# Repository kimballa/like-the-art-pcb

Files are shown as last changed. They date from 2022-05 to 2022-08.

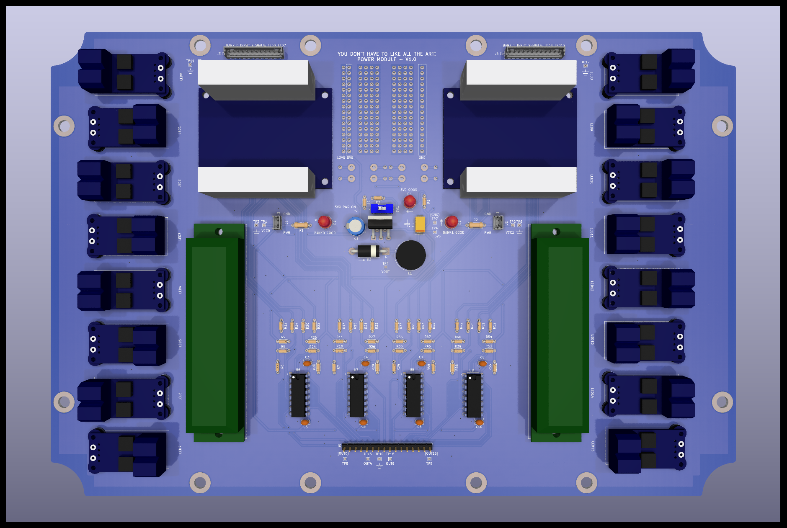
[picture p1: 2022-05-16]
lta-power-module/fab runs/lta-power-module-v1_0-2022-05-16/lta-power-module-v1_0 assembled board rendering.png

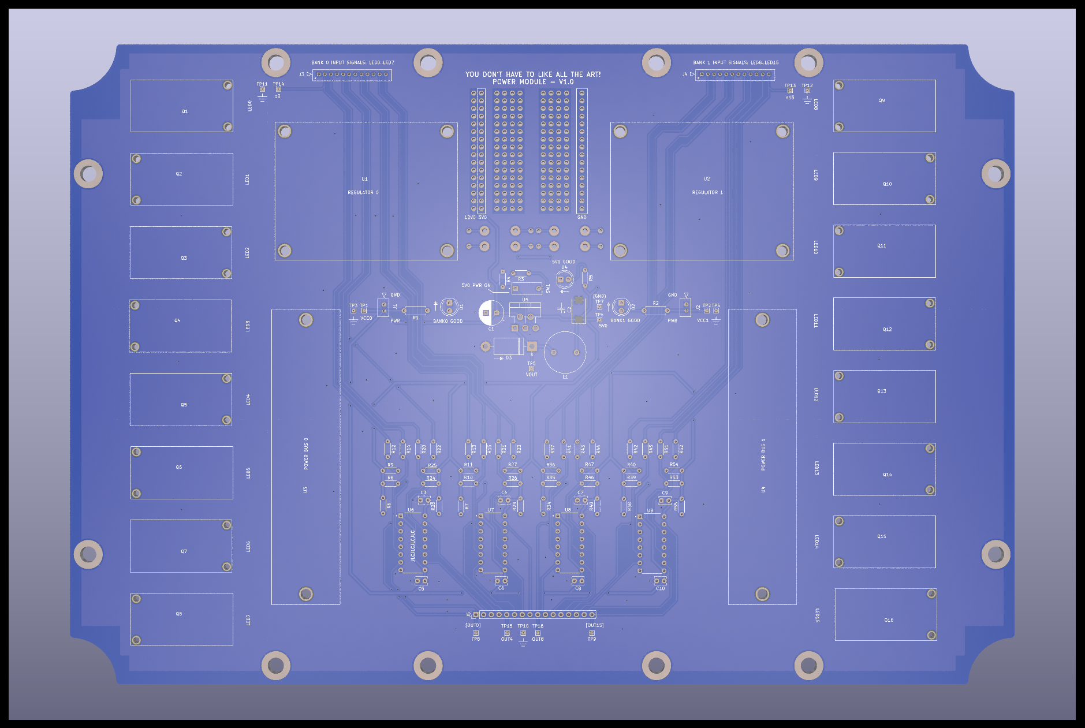
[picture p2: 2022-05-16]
lta-power-module/fab runs/lta-power-module-v1_0-2022-05-16/lta-power-module-v1_0 bare board rendering.png

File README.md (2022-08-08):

You Don't Have to Like All the Art! -- PCBs
===========================================

PCB designs and eCAD files for the "You Don't Have to Like All the Art!" project.

This system consists of two distinct circuit boards:

* `lta-logic-module` - The "logic" that determines when it's dark out / should be active, what
  messages to light up on the sign, manages PWM or other effects when displaying the sign, and
  also handles button inputs from users. Runs on a combination of 5V and 3V3. This is designed
  around a port for installing an Adafruit Feather M4 Express (ATSAMD51 / Cortex-M4) Arduino
  device. The rest of the circuitry:
  * Provides regulated 5V0 input voltage for the rest of this module
  * Manages a wide fanout of control and sense lines via I2C
  * Uses a phototransistor to sense when it is dark out, and thus the system should be active
    vs in standby mode
  * Combines the sign control lines with a global PWM signal and buffers the output before feeding
    to the power module.
* `lta-power-module` - The high-power circuits that actually drive the LED signs. This module is
  "dumb" and contains no combinational logic or more complex circuitry. Most of the board is used
  for mounting 3rd-party PCB submodules for high-amp 12V0 voltage regulation, distributing a
  power bus, and actually driving power MOSFETs linked to each sign's power wiring. The onboard
  circuitry:
  * Provides regulated 5V0 input voltage for the rest of the onboard circuitry
  * Displays condition of regulated 12V0 input power
  * Uses SN75374 low-side drivers to send control signals to the MOSFET modules
  * Contains a small integrated protoboard for in-field repairs and modifications

The `photodiode-sim` subproject is a simplified version of the `DARK` detection circuitry for use
with `ngspice` to understand the sensitivity of the logic signal to input current levels from the
phototransistor and the variable resistance of the potentiometer used as an in-field sensitivity
calibration input.

A third PCB (`mosfet-chip`) is a mini-PCB to connect two circuits via screw-terminals, switchable by
an onboard `IRLZ24` NMOS FET transistor activated by a separate gate pin. 16 of these are mounted on
the power module by #0 machine screws.

I originally used this
[High-Power Dual MOSFET Switch Module](https://protosupplies.com/product/high-power-dual-mosfet-switch-module/)
but found the screw terminals included were too unreliable. This PCB is footprint-compatible and
uses larger-gauge, higher-quality terminal blocks by Phoenix Contact. The `mosfet-chip/` directory
includes a panelized (2x3) layout suitable for PCBA and the BOM to enable assembly at JLCPCB.

Fabrication
-----------

All models are built with KiCAD 6. Each module contains a BOM spreadsheet for assembly with MPNs to
order from DigiKey or elsewhere as noted. Per-run fabrication gerbers are kept in versioned
subdirectories of each submodule project.

All modules are fabricated with the following parameters:

* 2 layers
* 1.6mm finished board thickness
* FR4-Tg130 core
* Both layers 1 oz copper thickness
* Blue soldermask, white silkscreen (these choices made only for aesthetic reasons and do not
  affect eng or mfg)

The logic module is fabricated with ENIG finish for reflow; the power module can be finished
with RoHS Pb-free HASL.

The logic module was fabricated by Elecrow and follows their design rules. Smallest
traces are 0.20mm. All trace separation >= 0.15mm.

The power module was fabricated by JLCPCB and follows their design rules. Smallest power module
traces and trace separations are 0.25mm / 0.20mm, which more than meets their capabilities.

Assembly
--------

Boards require only single-sided assembly.

The logic module is a mixed SMD/THT board and was assembled by Elecrow. Smallest reflow components
are 0603. Logic module ICs are SOIC (1.27mm pitch). Actual LEDs, resistors, and IC decoupling
capacitors do not follow the BOM strictly but instead use house parts (except as noted `Exact MPN
Only` in the BOM). More notes about logic module assembly are in `README-fab-and-pcba.txt` in
the logic module directory.

The power module is THT-only and intended for hand-soldered assembly. (A single 7343-metric / 2917
/ "size D" tantalum SMD capacitor for the 5V0 regulator can also be hand-soldered.)

The mosfet chips are a mixed SMD/THT assembly and were assembled by JLCPCB. BOM includes SPNs
for JLC's preferred supplier. Individual mini-PCBs are too small for automated SMD assembly,
so gerbers are supplied for a panelized 2x3 PCB layout, made with the Panelizer plugin for KiCAD 6.

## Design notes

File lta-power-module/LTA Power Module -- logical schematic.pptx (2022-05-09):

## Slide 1

Actual PCB-laid circuitry

2x MicroLatch 12-pin

2x12 c’tors w/
ext signals

Over header pins, 1 per FET driver
(Also to R + LED)

Power comes directly cabled into regulator, never through the board

12V regulator

12V regulator

Over flying wires

12-way terminal block

12V0

“PWR ON” LED

Also to board GND

“PWR ON” LED

Also to board GND

thru MicroLatch 2pin

5V0 regulator

thru MicroLatch 2pin

12-way terminal block

12V0

5V0

“go” @ 3V3

Over flying wires

4x SN75374

“go” @ 12V0

8x
FET drivers

To LED sign, via flying wires

8x
FET drivers

To LED sign, via flying wires

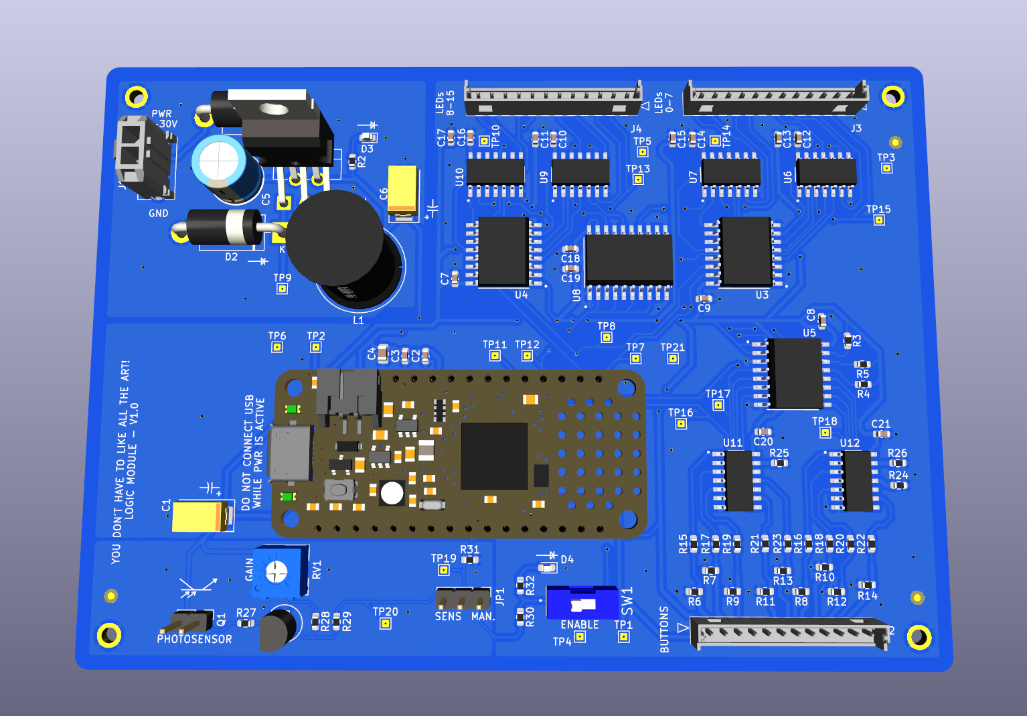
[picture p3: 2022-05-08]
lta-logic-module/fab runs/lta-logic-v1_0-2022-05-08/lta-logic-v1_0-2022-05-08-render.png

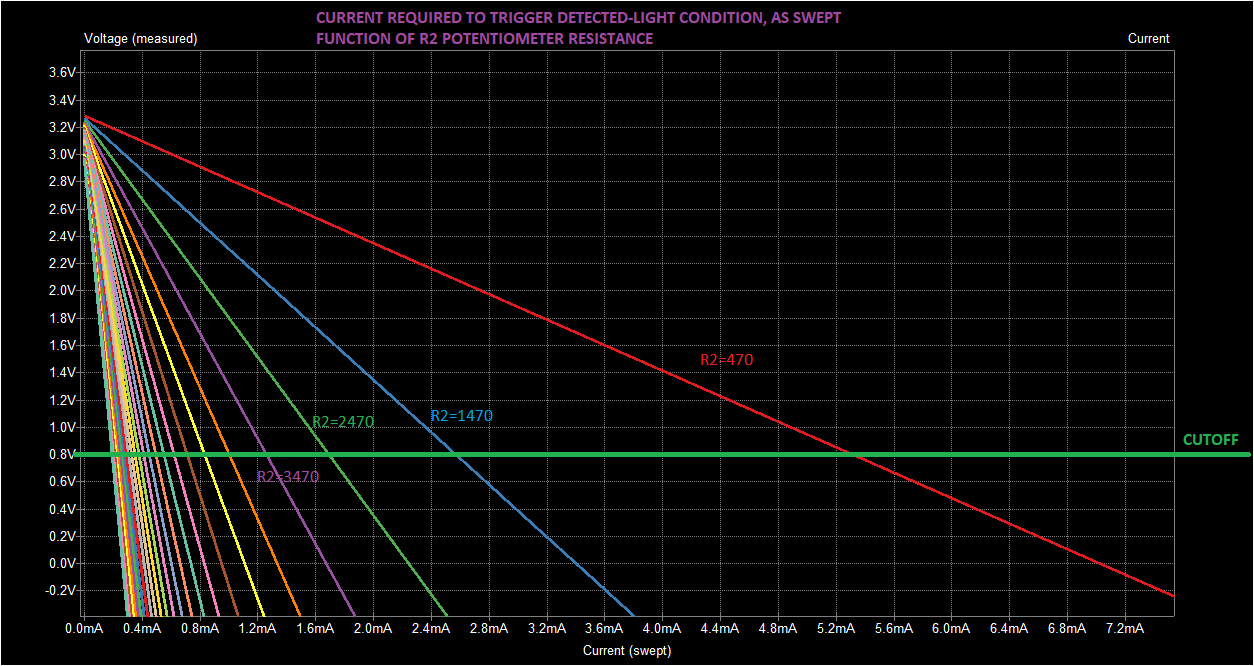
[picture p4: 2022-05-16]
photodiode-sim/sweep-analysis.png

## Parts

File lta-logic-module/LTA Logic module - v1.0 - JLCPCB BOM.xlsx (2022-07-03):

Reference | Value | Footprint | Datasheet | Comment | MANUFACTURER | MPN | SPN | Item Cost | QTY | BOM Cost
C1 | 22u | Capacitor_Tantalum_SMD:CP_EIA-7343-30_AVX-N | https://datasheets.kyocera-avx.com/X7RDielectric.pdf | 22u 10% >=16V 7343 ESR<=250mOhm solid tantalum | KYOCERA AVX | TPSD226K025R0200 | C444816 | $1.2335 | 1 | $1.2335 | SPN for 35V version; exact spec is C284839
C2, C7-C10, C12, C14, C16, C19-C21 | 100n | Capacitor_SMD:C_0603_1608Metric | https://datasheets.kyocera-avx.com/X7RDielectric.pdf | 100nF 5% 6.3V 0603 X7R ceramic; 20mOhm < ESR < 10 Ohm | KYOCERA | 06036C104JAT2A | C109474 | $0.0053 | 11 | $0.0583 | SPN for YAEGO equiv part @ 16V
C3, C11, C13, C15, C17, C18 | 1u | Capacitor_SMD:C_0603_1608Metric | https://datasheets.kyocera-avx.com/X7RDielectric.pdf | 1u 5% 16V 0603 X7R ceramic; 20mOhm < ESR < 10 Ohm | KYOCERA | 0603YC105JAT2A | C519560 | $0.0284 | 6 | $0.1704 | SPN for YAEGO equiv part
C4 | 4u7 | Capacitor_SMD:C_0805_2012Metric | https://datasheets.kyocera-avx.com/X7RDielectric.pdf | 4u7 5% 16V 0805 X7R ceramic; 20mOhm < ESR < 10 Ohm | KYOCERA | 0805YC475KAT2A | C513766 | $0.0272 | 1 | $0.0272 | SPN for alt. mfr; 25V 10%
C5 | 220u | Capacitor_THT:CP_Radial_D8.0mm_P3.50mm | https://content.kemet.com/datasheets/KEM_A4010_EST.pdf | 220u 20% 35V low-ESR (<=160mOhm), I_RMS>250mA aluminum | KEMET | EST227M035AG4AA | C440830 | $0.1048 | 1 | $0.1048 | SPN for Rubycon equivalent part
C6 | 68u | Capacitor_Tantalum_SMD:CP_EIA-7343-30_AVX-N | https://datasheets.kyocera-avx.com/TPS.pdf | 68u 10% AVX TPS 20V low-ESR (<=150mOhm) solid tantalum; exact MPN | KYOCERA AVX | TPSD686M020R0150 | C308898 | $2.9899 | 1 | $2.9899 | SPN for "E" case, 25V, 125 mOhm ESR (over-height; better voltage tol. / ESR; pricier)
D1 | SB5100 | Diode_THT:D_DO-201AD_P15.24mm_Horizontal | https://www.smc-diodes.com/propdf/SB5100%20N0092%20REV.B.pdf | Any 100V 5A Schottky diode, Vf <= 850mV | SMC Diode Solutions | SB5100 | C154717 | $0.5283 | 1 | $0.5283
D2 | SB530 | Diode_THT:D_DO-201AD_P15.24mm_Horizontal | https://www.vishay.com/docs/88721/sb520.pdf | 30V 5A Schottky diode, Vf <= 480mV. (Any SB530-xxx diode OK) | Vishay | SB530-E3/54 | C222506 | $0.8368 | 1 | $0.8368
D3 | PWR | LED_SMD:LED_0603_1608Metric | https://media.digikey.com/pdf/Data%20Sheets/Harvatek%20PDFs/B1931URO-20D000114U1930.pdf | Any Vf=2.0V I_test=20mA red LED OK | Harvatek | 3147-B1931URO-20D000114U1930CT-ND | C125099 | $0.0175 | 1 | $0.0175 | SPN for Lite-On LTST-C191KRKT
D4 | DARK_EN | LED_SMD:LED_0603_1608Metric | https://media.digikey.com/pdf/Data%20Sheets/Harvatek%20PDFs/B1931URO-20D000114U1930.pdf | Any Vf=2.0V I_test=20mA red LED OK | Harvatek | 3147-B1931URO-20D000114U1930CT-ND | C125099 | $0.0175 | 1 | $0.0175 | SPN for Lite-On LTST-C191KRKT
J1 | Molex-MicroFit_43650-0218 | Aaron_THT:Molex-Microfit-43650-0218 | https://www.molex.com/pdm_docs/ps/PS-43650.pdf | Molex Micro-Fit3, 2-pin | Molex | 436500218 | DNP |  | 1 | $0.0000
J2-J4 | Molex-MicroLatch_53253-1270 | Aaron_THT:Molex-MicroLatch-53253-1270 | https://www.molex.com/webdocs/datasheets/pdf/en-us/0532531270_PCB_HEADERS.pdf | Molex Micro-Latch, 12-pin | Molex | 532531270 | DNP |  | 3 | $0.0000
JP1 | Jumper_3_Open | Connector_PinHeader_2.54mm:PinHeader_1x03_P2.54mm_Vertical | ~ | Use 1x3 THT male pin header, gold mating, 2.54mm pitch |  |  | DNP |  | 1 | $0.0000
L1 | 150u | Aaron_THT:L_Radial_D13.5mm_P7.50mm | https://abracon.com/Magnetics/radial/AIUR-06.pdf | 150uH, Exact MFR/MPN required | Abracon LLC | AIUR-06-151K | DNP |  | 1 | $0.0000
Q1 | PT334-6B | Connector_PinHeader_2.54mm:PinHeader_1x02_P2.54mm_Vertical | https://media.digikey.com/pdf/Data%20Sheets/Everlight%20PDFs/PT334-6B.pdf | PT334 is externally-attached; mount 1x2 pin male header (2.54mm pitch, gold) here |  |  | DNP |  | 1 | $0.0000
Q2 | 2N3904 | Package_TO_SOT_THT:TO-92_Inline |  | Any 2N3904 TO-92 transistor OK | Central Semiconductor | 2N3904 PBFREE | C2081 | $0.0317 | 1 | $0.0317
R1, R6-R14, R24-R26 | 10K | Resistor_SMD:R_0603_1608Metric | ~ | 10K 0603 resistor; +/-1%; 1/10W | YAEGO | RC0603FR-0710KL | C25804 | $0.0012 | 13 | $0.0156 | SPN for JLC basic part - UNI-ROYAL equiv
R2 | 330R | Resistor_SMD:R_0603_1608Metric | ~ | 330R 0603 resistor; +/-1%; 1/10W | YAEGO | RC0603FR-07330RL | C23138 | $0.0012 | 1 | $0.0012 | SPN for JLC basic part - UNI-ROYAL equiv
R3-R5, R27, R30 | 4K7 | Resistor_SMD:R_0603_1608Metric | ~ | 4K7 0603 resistor; +/-1%; 1/10W | YAEGO | RC0603FR-074K7L | C23162 | $0.0012 | 5 | $0.0060 | SPN for JLC basic part - UNI-ROYAL equiv
R15-R23, R28 | 470R | Resistor_SMD:R_0603_1608Metric | ~ | 470R 0603 resistor; +/-1%; 1/10W | YAEGO | RC0603FR-07470RL | C23179 | $0.0012 | 10 | $0.0120 | SPN for JLC basic part - UNI-ROYAL equiv
R29 | 220R | Resistor_SMD:R_0603_1608Metric | ~ | 220R 0603 resistor; +/-1%; 1/10W | YAEGO | RC0603FR-07220RL | C22962 | $0.0012 | 1 | $0.0012 | SPN for JLC basic part - UNI-ROYAL equiv
R31 | 220K | Resistor_SMD:R_0603_1608Metric | ~ | 220K 0603 resistor; +/-1%; 1/10W | YAEGO | RC0603FR-07220KL | C22961 | $0.0012 | 1 | $0.0012 | SPN for JLC basic part - UNI-ROYAL equiv
R32 | 120R | Resistor_SMD:R_0603_1608Metric | ~ | 120R 0603 resistor; +/-1%; 1/10W | YAEGO | RC0603FR-07120RL | C22787 | $0.0012 | 1 | $0.0012 | SPN for JLC basic part - UNI-ROYAL equiv
RV1 | 25K | Aaron_THT:TRIM_3362P | https://www.bourns.com/docs/Product-Datasheets/3362.pdf | Any 25KOhm trimpot w/ same footprint OK | Bourns | 3362P-1-253LF | C81264 | $0.2587 | 1 | $0.2587 | SPN for 50 KOhm version
SW1 | SW_SPST | Aaron_THT:CUI-DIP-SW_DS01-254-x-01xx | https://www.cuidevices.com/product/resource/ds01-254.pdf | Any 1x SPST THT dip switch w/ same footprint OK | CUI Devices | DS01-254-S-01BE | C129067 | $0.2913 | 1 | $0.2913 | SPN for alt. mfr
U1 | Feather_M4_Express | aaron-imported-parts:Arduino_Feather_M4_Express_PinHeaders |  | Use 1x16 and 1x12 female THT headers, gold mating, 2.54mm pitch, 6.5--8.0mm tall |  |  | DNP |  | 1 | $0.0000
U2 | LM2595T-5 | Aaron_THT:TO-220-5_P3.4x3.7mm_StaggerOdd_Lead3.8mm_Vertical-SilkFix | http://www.ti.com.cn/cn/lit/ds/symlink/lm2595.pdf | Exact MFR/MPN required | Texas Instruments | LM2595T-5.0/NOPB | C2868897 | $3.7600 | 1 | $3.7600 | no stock; can be hand-soldered @ home.
U3-U5 | PCF8574DW | Aaron_TI_Parts:TI_SOIC_DW0016A | https://www.ti.com/lit/ds/symlink/pcf8574.pdf | Exact MFR/MPN required | Texas Instruments | PCF8574DW | C7605 | $1.7709 | 3 | $5.3127 | SPN for NXP equiv; 2x-check footprint. Exact MPN is C1542490 but no stock
U6, U7, U9, U10 | SN74LVC00AD | Aaron_TI_Parts:TI_SOIC_D_R-PDSO-G14 | https://www.ti.com/lit/ds/symlink/sn74lvc00a.pdf | Exact MFR/MPN required | Texas Instruments | SN74LVC00AD | C485072 | $0.2214 | 4 | $0.8856
U8 | SN74LVC244ADWR | Aaron_TI_Parts:TI_SOIC_DW0020A | https://www.ti.com/lit/ds/symlink/sn74lvc244a.pdf | Exact MFR/MPN required; -ADW or -ADWR packaging OK. | Texas Instruments | SN74LVC244ADWR | C507250 | $0.4869 | 1 | $0.4869
U11, U12 | SN74LVC14AD | Aaron_TI_Parts:TI_SOIC_D_R-PDSO-G14 | https://www.ti.com/lit/ds/symlink/sn74lvc14a.pdf | Exact MFR/MPN required | Texas Instruments | SN74LVC14AD | C133541 | $0.2196 | 2 | $0.4392

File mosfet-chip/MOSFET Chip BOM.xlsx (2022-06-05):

Reference | Value | Footprint | Datasheet | Comment | JLCPCB_PN | MANUFACTURER | MPN | SPN | Qty
D1 | XL-1608SURC-06 | LED_SMD:LED_0603_1608Metric | https://datasheet.lcsc.com/lcsc/2012301032_XINGLIGHT-XL-1608SURC-06_C965799.pdf |  | C965799 | XINGLIGHT | XL-1608SURC-06 |  | 1
> H1, H2 | MountingHole | Aaron_Pads:MountingHole_80mil | ~ |  |  |  |  |  | 2
J1 | Conn_01x02 | Connector_PinHeader_2.54mm:PinHeader_1x02_P2.54mm_Vertical | ~ | 0.1" gold male header pins | DNP | TE Connectivity AMP Connectors | 5-146858-1 | A105469CT-ND | 1
> J2, J3 | Screw_Terminal_01x02 | Aaron_Phoenix_Parts:Phoenix_1x02_1711725 | https://media.digikey.com/pdf/Data%20Sheets/Phoenix%20Contact%20PDFs/1711725.pdf |  | C89120 | Phoenix Contact | 1711725 | 277-1027-ND | 2
Q1 | ${FET_PART} | Package_TO_SOT_THT:TO-220-3_Vertical | https://www.infineon.com/dgdl/irlz34npbf.pdf?fileId=5546d462533600a40153567206892720 |  | C513144 | Infineon | IRLZ34NPbF | IRLZ34NPBF-ND | 1
R1 | 100R | Resistor_SMD:R_0603_1608Metric |  | 100R 1% 1/10W | C22775 | UNI-ROYAL | 0603WAF1000T5E |  | 1
R2 | 10K | Resistor_SMD:R_0603_1608Metric |  | 10K 1% 1/10W | C25804 | UNI-ROYAL | 0603WAF1002T5E |  | 1
R3 | 3K3 | Resistor_SMD:R_0603_1608Metric |  | 3K3 1% 1/10W | C22978 | UNI-ROYAL | 0603WAF3301T5E |  | 1

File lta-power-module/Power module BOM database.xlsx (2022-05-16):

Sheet: PCB BOM
Reference | Value | Footprint | Datasheet | Comment | MANUFACTURER | MPN | SPN | Supplier | Qty
C1 | 220u | Capacitor_THT:CP_Radial_D8.0mm_P3.50mm | https://content.kemet.com/datasheets/KEM_A4010_EST.pdf | 220u 20% 35V low-ESR (<=160mOhm), I_RMS>250mA aluminum | KEMET | EST227M035AG4AA | 399-6615-ND | DigiKey | 1
C2 | 68u | Capacitor_Tantalum_SMD:CP_EIA-7343-30_AVX-N_Pad2.25x2.55mm_HandSolder | https://datasheets.kyocera-avx.com/TPS.pdf | 68u 10% AVX TPS 20V low-ESR (<=150mOhm) solid tantalum; exact MPN | KYOCERA AVX | TPSD686M020R0150 | 478-9217-1-ND | DigiKey | 1
> C3-C10 | 1u | Capacitor_THT:C_Disc_D3.8mm_W2.6mm_P2.50mm | https://connect.kemet.com:7667/gateway/IntelliData-ComponentDocumentation/1.0/download/datasheet/C315C105K3R5TA7303 | 1u X7R 25V low-ESR THT | KEMET | C315C105K3R5TA7303 | 399-C315C105K3R5TA7303CT-ND | DigiKey | 8
D1 | PWR0 | Aaron_THT:LED_D5.0mm_SilkFix | https://cree-led.com/media/documents/C5SMF-RJF-RJE-GJF-GJE-BJF-BJE-1240.pdf | Vf=2.0V I_test=20mA red LED 5mm THT | CreeLED | C5SMF-RJF-CT0W0BB1 | C5SMF-RJF-CT0W0BB1-ND | DigiKey | 1
D2 | PWR1 | Aaron_THT:LED_D5.0mm_SilkFix | https://cree-led.com/media/documents/C5SMF-RJF-RJE-GJF-GJE-BJF-BJE-1240.pdf | Vf=2.0V I_test=20mA red LED 5mm THT | CreeLED | C5SMF-RJF-CT0W0BB1 | C5SMF-RJF-CT0W0BB1-ND | DigiKey | 1
D3 | SB530 | Diode_THT:D_DO-201AD_P15.24mm_Horizontal | https://www.vishay.com/docs/88721/sb520.pdf | 30V 5A Schottky diode, Vf <= 480mV. (Any SB530-xxx diode OK) | Vishay | SB530-E3/54 | SB530-E3/54GICT-ND | DigiKey | 1
D4 | 5V0PWR | Aaron_THT:LED_D5.0mm_SilkFix | https://cree-led.com/media/documents/C5SMF-RJF-RJE-GJF-GJE-BJF-BJE-1240.pdf | Vf=2.0V I_test=20mA red LED 5mm THT | CreeLED | C5SMF-RJF-CT0W0BB1 | C5SMF-RJF-CT0W0BB1-ND | DigiKey | 1
> H1-H12 | MountingHole_Pad | MountingHole:MountingHole_5.3mm_M5_ISO7380_Pad | ~ | M5 screw mounting hole, ISO 7380 pad |  |  |  |  | 12
> J1, J2 | Molex-MicroLatch-53253-0270 | Aaron_THT:Molex-MicroLatch-53253-0270 | https://www.molex.com/webdocs/datasheets/pdf/en-us/0532530270_PCB_HEADERS.pdf | 2-pin header for power (regulator out) | Molex | 532530270 | WM19004-ND | DigiKey | 2
> J3, J4 | Molex-MicroLatch-53253-1270 | Aaron_THT:Molex-MicroLatch-53253-1270 | https://www.molex.com/webdocs/datasheets/pdf/en-us/0532531270_PCB_HEADERS.pdf | 12-pin signal connector | Molex | 532531270 | WM24308-ND | DigiKey | 2
J5 | Conn_01x16 | Connector_PinHeader_2.54mm:PinHeader_1x16_P2.54mm_Vertical | ~ | standard male 2.54mm gold THT header pin row | TE Connectivity AMP Connectors | 5-146858-1 | A105469CT-ND | DigiKey | 1
> J6, J8-J17, J19, J20, J22-J31, J34, J36-J45, J47, J48, J50-J59, J61-J69, J71, J72, J74-J83, J86, J88-J97, J99-J107, J109, J110, J112-J121, J123, J124, J126-J135, J138, J140-J149, J152-J159, J161, J162, J164-J173, J176, J178-J187, J190, J192-J201, J204-J211, J214, J216-J218, J220-J222, J224-J226, J228, J229 | Conn_01x01 | Aaron_Pads:1mm_PTH_No_Silk | ~ | standard 1mm PTH for prototyping |  |  |  |  | 184
> J18, J46, J60, J70, J98, J108, J122, J160 | Conn_01x01 | Aaron_Pads:1.6mm_PTH_No_Silk | ~ | larger 1.6mm holes for DO201 diodes, larger capacitors |  |  |  |  | 8
L1 | 150u | Aaron_THT:L_Radial_D13.5mm_P7.50mm | https://abracon.com/Magnetics/radial/AIUR-06.pdf | 150uH, Exact MFR/MPN required | Abracon LLC | AIUR-06-151K | 535-13029-ND | DigiKey | 1
> Q1-Q16 | Dual_MOSFET_Switch_Module | lta-power-footprints:Dual_MOSFET_Driver | https://protosupplies.com/product/high-power-dual-mosfet-switch-module/ | Dual MOSFET driver board w/ mounting holes |  |  | B07XJSRY6B | Amazon | 16
> R1, R2 | 1K, 1/4W | Resistor_THT:R_Axial_DIN0207_L6.3mm_D2.5mm_P7.62mm_Horizontal |  | 1K THT resistor; +/-5%; 1/4W | Stackpole | CF14JT1K00 | CF14JT1K00CT-ND | DigiKey | 2
> R3, R4 | 10K | Resistor_THT:R_Axial_DIN0204_L3.6mm_D1.6mm_P5.08mm_Horizontal | ~ | 10K THT resistor; +/-5%; 1/8W | Stackpole | CF18JT10K0 | CF18JT10K0CT-ND | DigiKey | 2
R5 | 330R | Resistor_THT:R_Axial_DIN0204_L3.6mm_D1.6mm_P5.08mm_Horizontal |  | 330R THT resistor; +/-5%; 1/8W | Stackpole | CF18JT330R | CF18JT330RCT-ND | DigiKey | 1
> R12-R15, R20-R23, R37, R41-R45, R51, R52 | 33R | Resistor_THT:R_Axial_DIN0204_L3.6mm_D1.6mm_P5.08mm_Horizontal | ~ | 33R THT resistor; +/-5%; 1/8W | Stackpole | CF18JT33R0 | CF18JT33R0CT-ND | DigiKey | 16
> R6, R7, R28, R29, R34, R38, R48, R55 | 220R | Resistor_THT:R_Axial_DIN0204_L3.6mm_D1.6mm_P5.08mm_Horizontal | ~ | 220R THT resistor; +/-5%; 1/8W | Stackpole | CF18JT220R | CF18JT220RCT-ND | DigiKey | 8
> R8-R11, R24-R27, R35, R36, R39, R40, R46, R47, R53, R54 | 2K2 | Resistor_THT:R_Axial_DIN0204_L3.6mm_D1.6mm_P5.08mm_Horizontal | ~ | 2K2 THT resistor; +/-5%; 1/8W | Stackpole | CF18JT2K20 | CF18JT2K20CT-ND | DigiKey | 16
SW1 | SW_SPST | Aaron_THT:CUI-DIP-SW_DS01-254-x-01xx | https://www.cuidevices.com/product/resource/ds01-254.pdf | Any 1x SPST THT dip switch w/ same footprint OK | CUI Devices | DS01-254-S-01BE | 2223-DS01-254-S-01BE-ND | DigiKey | 1
> TP1-TP16 | TestPoint_Flag | Aaron_THT:TestPoint_THTPad_1.0x1.0mm_Drill0.3mm | ~ |  |  |  |  |  | 16
> U1, U2 | DIYMORE_20A_Step_Down | lta-power-footprints:12V_regulator | https://www.amazon.com/dp/B07Y7YB14L?psc=1&ref=ppx_yo2ov_dt_b_product_details |  | DIYMORE |  | B07Y7YB14L | Amazon | 2
> U3, U4 | OONO_16A_12pos_Terminal_Block | lta-power-footprints:12-way_power_distribution_bus | https://www.amazon.com/dp/B08TBXQ7H6?psc=1&smid=A2OVMUS055KMW5&ref_=chk_typ_imgToDp |  |  |  | B08TBXQ7H6 | Amazon | 2
U5 | LM2595T-5 | Aaron_THT:TO-220-5_P3.4x3.7mm_StaggerOdd_Lead3.8mm_Vertical-SilkFix | http://www.ti.com.cn/cn/lit/ds/symlink/lm2595.pdf | Exact MFR/MPN required | Texas Instruments | LM2595T-5.0/NOPB | LM2595T-5.0/NOPB-ND | DigiKey | 1
> U6-U9 | SN75374N | Aaron_TI_Parts:TI_N_R-PDIP-T16 | https://www.ti.com/lit/ds/symlink/sn75374.pdf |  | Texas Instruments | SN75374N | 296-34130-5-ND | DigiKey | 4

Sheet: Assembly BOM Items
Reference | Value | Description | Comment | Datasheet | MANUFACTURER | MPN | SPN | Supplier | Qty
J1, J2, J3, J4 |  | Micro-Latch female crimp terminal, 24--30AWG | Get a bunch of overage. Fragile, and great price break. Get like 200. |  | Molex | 502128000 | WM4561CT-ND | DigiKey | 64 | includes 1 power + 1 logic pcb's worth.
J1, J2 |  | Micro-Latch 2-pin female crimp housing for connector |  |  | Molex | 510650200 | WM19009-ND | DigiKey | 2
J3, J4 + 3xLOGIC |  | Micro-Latch 12-pin female crimp housing for connector |  |  | Molex | 510651200 | WM24300-ND | DigiKey | 5 | 2 for power PCB, 3 for logic PCB
(for logic board) |  | Micro-Fit 3.0 Female-to-Pigtail Cable Assembly, 2 leads, 150.00mm | For logic board; 18AWG | https://www.molex.com/webdocs/datasheets/pdf/en-us/2147511021_CABLE_ASSEMBLIES.pdf | Molex | 2147511021 | 900-2147511021-ND | DigiKey | 2
(spares for logic board) |  | PT334-6B photo-transistor | Spares |  | Everlight Electronics Co | PT334-6B | 1080-1158-ND | DigiKey | 4

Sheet: DigiKey-order-2022-05-10
Purpose | Part | MPN | SPN | Qty/Board | Overage | Total Qty | Digikey Order Line
PCBA BOM | 220u 20% 35V low-ESR (<=160mOhm), I_RMS>250mA aluminum | EST227M035AG4AA | 399-6615-ND | 1 | 2 | 4 | 4,399-6615-ND,
PCBA BOM | 68u 10% AVX TPS 20V low-ESR (<=150mOhm) solid tantalum; exact MPN | TPSD686M020R0150 | 478-9217-1-ND | 1 | 2 | 4 | 4,478-9217-1-ND,
PCBA BOM | 1u X7R 25V low-ESR THT | C315C105K3R5TA7303 | 399-C315C105K3R5TA7303CT-ND | 8 | 4 | 20 | 20,399-C315C105K3R5TA7303CT-ND,
PCBA BOM | Vf=2.0V I_test=20mA red LED 5mm THT | C5SMF-RJF-CT0W0BB1 | C5SMF-RJF-CT0W0BB1-ND | 3 | 4 | 10 | 10,C5SMF-RJF-CT0W0BB1-ND,
PCBA BOM | 30V 5A Schottky diode, Vf <= 480mV. (Any SB530-xxx diode OK) | SB530-E3/54 | SB530-E3/54GICT-ND | 1 | 1 | 3 | 3,SB530-E3/54GICT-ND,
PCBA BOM | Molex 2-pin microlatch | 532530270 | WM19004-ND | 2 | 1 | 5 | 5,WM19004-ND,
PCBA BOM | Molex 12-pin microlatch | 532531270 | WM24308-ND | 2 | 1 | 5 | 5,WM24308-ND,
PCBA BOM | standard male 2.54mm gold THT header pin row | 5-146858-1 | A105469CT-ND | 16 | 68 | 100 | 100,A105469CT-ND,
PCBA BOM | 150uH, Exact MFR/MPN required | AIUR-06-151K | 535-13029-ND | 1 | 1 | 3 | 3,535-13029-ND,
PCBA BOM | 1K THT resistor; +/-5%; 1/4W | CF14JT1K00 | CF14JT1K00CT-ND | 2 | 6 | 10 | 10,CF14JT1K00CT-ND,
PCBA BOM | 10K THT resistor; +/-5%; 1/8W | CF18JT10K0 | CF18JT10K0CT-ND | 2 | 6 | 10 | 10,CF18JT10K0CT-ND,
PCBA BOM | 330R THT resistor; +/-5%; 1/8W | CF18JT330R | CF18JT330RCT-ND | 1 | 8 | 10 | 10,CF18JT330RCT-ND,
PCBA BOM | 220R THT resistor; +/-5%; 1/8W | CF18JT220R | CF18JT220RCT-ND | 8 | 9 | 25 | 25,CF18JT220RCT-ND,
PCBA BOM | 33R THT resistor; +/-5%; 1/8W | CF18JT33R0 | CF18JT33R0CT-ND | 16 | 18 | 50 | 50,CF18JT33R0CT-ND,
PCBA BOM | 2K2 THT resistor; +/-5%; 1/8W | CF18JT2K20 | CF18JT2K20CT-ND | 16 | 18 | 50 | 50,CF18JT2K20CT-ND,
PCBA BOM | 1x SPST THT dip switch | DS01-254-S-01BE | 2223-DS01-254-S-01BE-ND | 1 | 1 | 3 | 3,2223-DS01-254-S-01BE-ND,
PCBA BOM | 5V buck regulator | LM2595T-5.0/NOPB | LM2595T-5.0/NOPB-ND | 1 | 1 | 3 | 3,LM2595T-5.0/NOPB-ND,
PCBA BOM | FET driver | SN75374N | 296-34130-5-ND | 4 | 2 | 10 | 10,296-34130-5-ND,
Tools | trimpot adjuster tool | H-90 | H90-ND | 0 | 1 | 1 | 1,H90-ND,
general order | Basic NPN transistor | BC546BTF | BC546BTFCT-ND | 0 | 4 | 4 | 4,BC546BTFCT-ND,
general order | Basic NPN transistor | 2N3904 PBFREE | 1514-2N3904PBFREE-ND | 0 | 4 | 4 | 4,1514-2N3904PBFREE-ND,
general order | Basic NPN transistor | PN2222TF | PN2222TFCT-ND | 0 | 4 | 4 | 4,PN2222TFCT-ND,
general order | Basic PNP transistor | PN2907ATF | PN2907ATFCT-ND | 0 | 4 | 4 | 4,PN2907ATFCT-ND,
general order | Basic PNP transistor | BC557BTF | BC557BTFCT-ND | 0 | 4 | 4 | 4,BC557BTFCT-ND,
general order | Basic PNP transistor | 2N3906-G | 641-1946-ND | 0 | 4 | 4 | 4,641-1946-ND,
general order | 25KOhm single-turn trimpot | 3362P-1-253LF | 3362P-253LF-ND | 0 | 2 | 2 | 2,3362P-253LF-ND,
general order | 12V 1A fixed buck regulator | LM2675N-12/NOPB | LM2675N-12/NOPB-ND | 0 | 1 | 1 | 1,LM2675N-12/NOPB-ND,
Extended PCBA | Micro-Latch female crimp terminal, 24--30AWG | 502128000 | WM4561CT-ND | 28 | 144 | 200 | 200,WM4561CT-ND,
Extended PCBA | Micro-Latch 2-pin female crimp housing for connector | 510650200 | WM19009-ND | 2 | 1 | 5 | 5,WM19009-ND,
Extended PCBA | Micro-Latch 12-pin female crimp housing for connector | 510651200 | WM24300-ND | 2 | 3 | 7 | 7,WM24300-ND,
general order | Micro-Fit 3.0 Female-to-Pigtail Cable Assembly, 2 leads, 150.00mm | 2147511021 | 900-2147511021-ND | 0 | 2 | 2 | 2,900-2147511021-ND,
general order | PT334-6B photo-transistor | PT334-6B | 1080-1158-ND | 0 | 4 | 4 | 4,1080-1158-ND,

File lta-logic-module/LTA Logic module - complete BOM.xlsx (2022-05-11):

Reference | Value | Footprint | Datasheet | Comment | MANUFACTURER | MPN | QTY
C1 | 22u | Capacitor_Tantalum_SMD:CP_EIA-7343-30_AVX-N | https://datasheets.kyocera-avx.com/X7RDielectric.pdf | 22u 10% >=16V 7343 ESR<=250mOhm solid tantalum | KYOCERA AVX | TPSD226K025R0200 | 1
> C2, C7-C10, C12, C14, C16, C19-C21 | 100n | Capacitor_SMD:C_0603_1608Metric | https://datasheets.kyocera-avx.com/X7RDielectric.pdf | 100nF 5% 6.3V 0603 X7R ceramic; 20mOhm < ESR < 10 Ohm | KYOCERA | 06036C104JAT2A | 11
> C3, C11, C13, C15, C17, C18 | 1u | Capacitor_SMD:C_0603_1608Metric | https://datasheets.kyocera-avx.com/X7RDielectric.pdf | 1u 5% 16V 0603 X7R ceramic; 20mOhm < ESR < 10 Ohm | KYOCERA | 0603YC105JAT2A | 6
C4 | 4u7 | Capacitor_SMD:C_0805_2012Metric | https://datasheets.kyocera-avx.com/X7RDielectric.pdf | 4u7 5% 16V 0805 X7R ceramic; 20mOhm < ESR < 10 Ohm | KYOCERA | 0805YC475KAT2A | 1
C5 | 220u | Capacitor_THT:CP_Radial_D8.0mm_P3.50mm | https://content.kemet.com/datasheets/KEM_A4010_EST.pdf | 220u 20% 35V low-ESR (<=160mOhm), I_RMS>250mA aluminum | KEMET | EST227M035AG4AA | 1
C6 | 68u | Capacitor_Tantalum_SMD:CP_EIA-7343-30_AVX-N | https://datasheets.kyocera-avx.com/TPS.pdf | 68u 10% AVX TPS 20V low-ESR (<=150mOhm) solid tantalum; exact MPN | KYOCERA AVX | TPSD686M020R0150 | 1
D1 | SB5100 | Diode_THT:D_DO-201AD_P15.24mm_Horizontal | https://www.smc-diodes.com/propdf/SB5100%20N0092%20REV.B.pdf | Any 100V 5A Schottky diode, Vf <= 850mV | SMC Diode Solutions | SB5100 | 1
D2 | SB530 | Diode_THT:D_DO-201AD_P15.24mm_Horizontal | https://www.vishay.com/docs/88721/sb520.pdf | 30V 5A Schottky diode, Vf <= 480mV. (Any SB530-xxx diode OK) | Vishay | SB530-E3/54 | 1
D3 | PWR | LED_SMD:LED_0603_1608Metric | https://media.digikey.com/pdf/Data%20Sheets/Harvatek%20PDFs/B1931URO-20D000114U1930.pdf | Vf=2.0V I_test=20mA red LED | Harvatek | 3147-B1931URO-20D000114U1930CT-ND | 1
D4 | DARK_EN | LED_SMD:LED_0603_1608Metric | https://media.digikey.com/pdf/Data%20Sheets/Harvatek%20PDFs/B1931URO-20D000114U1930.pdf | Vf=2.0V I_test=20mA red LED | Harvatek | 3147-B1931URO-20D000114U1930CT-ND | 1
> FID1-FID3 | Fiducial | Fiducial:Fiducial_1mm_Mask2mm | ~ |  |  |  | 3
> H1-H4 | MountingHole_Pad | MountingHole:MountingHole_2.2mm_M2_ISO7380_Pad | ~ |  |  |  | 4
J1 | Molex-MicroFit_43650-0218 | Aaron_THT:Molex-Microfit-43650-0218 | https://www.molex.com/pdm_docs/ps/PS-43650.pdf | Molex Micro-Fit3, 2-pin | Molex | 436500218 | 1
> J2-J4 | Molex-MicroLatch_53253-1270 | Aaron_THT:Molex-MicroLatch-53253-1270 | https://www.molex.com/webdocs/datasheets/pdf/en-us/0532531270_PCB_HEADERS.pdf | Molex Micro-Latch, 12-pin | Molex | 532531270 | 3
JP1 | Jumper_3_Open | Connector_PinHeader_2.54mm:PinHeader_1x03_P2.54mm_Vertical | ~ | Use 1x3 THT male pin header, gold mating, 2.54mm pitch |  |  | 1
L1 | 150u | Aaron_THT:L_Radial_D13.5mm_P7.50mm | https://abracon.com/Magnetics/radial/AIUR-06.pdf | 150uH, Exact MFR/MPN required | Abracon LLC | AIUR-06-151K | 1
Q1 | PT334-6B | Connector_PinHeader_2.54mm:PinHeader_1x02_P2.54mm_Vertical | https://media.digikey.com/pdf/Data%20Sheets/Everlight%20PDFs/PT334-6B.pdf | PT334 is externally-attached; mount 1x2 pin male header (2.54mm pitch, gold) here | Everlight | PT334-6B | 1
Q2 | 2N3904 | Package_TO_SOT_THT:TO-92_Inline |  | Any 2N3904 TO-92 transistor OK | Central Semiconductor | 2N3904 PBFREE | 1
> R1, R6-R14, R24-R26 | 10K | Resistor_SMD:R_0603_1608Metric | ~ | 10K 0603 resistor; +/-1%; 1/10W | YAEGO | RC0603FR-0710KL | 13
R2 | 330R | Resistor_SMD:R_0603_1608Metric | ~ | 330R 0603 resistor; +/-1%; 1/10W | YAEGO | RC0603FR-07330RL | 1
> R3-R5, R27, R30 | 4K7 | Resistor_SMD:R_0603_1608Metric | ~ | 4K7 0603 resistor; +/-1%; 1/10W | YAEGO | RC0603FR-074K7L | 5
> R15-R23, R28 | 470R | Resistor_SMD:R_0603_1608Metric | ~ | 470R 0603 resistor; +/-1%; 1/10W | YAEGO | RC0603FR-07470RL | 10
R29 | 220R | Resistor_SMD:R_0603_1608Metric | ~ | 220R 0603 resistor; +/-1%; 1/10W | YAEGO | RC0603FR-07220RL | 1
R31 | 220K | Resistor_SMD:R_0603_1608Metric | ~ | 220K 0603 resistor; +/-1%; 1/10W | YAEGO | RC0603FR-07220KL | 1
R32 | 120R | Resistor_SMD:R_0603_1608Metric | ~ | 120R 0603 resistor; +/-1%; 1/10W | YAEGO | RC0603FR-07120RL | 1
RV1 | 25K | Aaron_THT:TRIM_3362P | https://www.bourns.com/docs/Product-Datasheets/3362.pdf | Any 25KOhm trimpot w/ same footprint OK | Bourns | 3362P-1-253LF | 1
SW1 | SW_SPST | Aaron_THT:CUI-DIP-SW_DS01-254-x-01xx | https://www.cuidevices.com/product/resource/ds01-254.pdf | Any 1x SPST THT dip switch w/ same footprint OK | CUI Devices | DS01-254-S-01BE | 1
> TP1-TP21 | TestPoint_Flag | Aaron_THT:TestPoint_THTPad_1.0x1.0mm_Drill0.3mm | ~ |  |  |  | 21
> TP22, TP23, TP26 | Thief | Aaron_Pads:Pad_1.5x1.5mm | ~ |  |  |  | 3
> TP24, TP25, TP27 | Thief | Aaron_Pads:Pad_D1.0mm | ~ |  |  |  | 3
U1 | Feather_M4_Express | aaron-imported-parts:Arduino_Feather_M4_Express_PinHeaders |  | Use 1x16 and 1x12 female THT headers, gold mating, 2.54mm pitch, 6.5--8.0mm tall |  |  | 1
U2 | LM2595T-5 | Aaron_THT:TO-220-5_P3.4x3.7mm_StaggerOdd_Lead3.8mm_Vertical-SilkFix | http://www.ti.com.cn/cn/lit/ds/symlink/lm2595.pdf | Exact MFR/MPN required | Texas Instruments | LM2595T-5.0/NOPB | 1
> U3-U5 | PCF8574DW | Aaron_TI_Parts:TI_SOIC_DW0016A | https://www.ti.com/lit/ds/symlink/pcf8574.pdf | Exact MFR/MPN required | Texas Instruments | PCF8574DW | 3
> U6, U7, U9, U10 | SN74LVC00AD | Aaron_TI_Parts:TI_SOIC_D_R-PDSO-G14 | https://www.ti.com/lit/ds/symlink/sn74lvc00a.pdf | Exact MFR/MPN required | Texas Instruments | SN74LVC00AD | 4
U8 | SN74LVC244ADWR | Aaron_TI_Parts:TI_SOIC_DW0020A | https://www.ti.com/lit/ds/symlink/sn74lvc244a.pdf | Exact MFR/MPN required; -ADW or -ADWR packaging OK. | Texas Instruments | SN74LVC244ADWR | 1
> U11, U12 | SN74LVC14AD | Aaron_TI_Parts:TI_SOIC_D_R-PDSO-G14 | https://www.ti.com/lit/ds/symlink/sn74lvc14a.pdf | Exact MFR/MPN required | Texas Instruments | SN74LVC14AD | 2

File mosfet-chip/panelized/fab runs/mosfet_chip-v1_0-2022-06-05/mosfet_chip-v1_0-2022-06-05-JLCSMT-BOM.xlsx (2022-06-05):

Designator | Comment | Footprint | JLCPCB Part # | MANUFACTURER | MPN | Qty
D1 | XL-1608SURC-06 | 0603 | C965799 | XINGLIGHT | XL-1608SURC-06 | 6
J2, J3 | 5.08mm pitch screw terminal, 2 pos | Aaron_Phoenix_Parts:Phoenix_1x02_1711725 | C89120 | Phoenix Contact | 1711725 | 12
Q1 | IRLZ34 TO-220 THT Power MOSFET | TO-220-3 | C513144 | Infineon | IRLZ34NPbF | 6
R1 | 100R 1% 1/10W (substitute MPN OK) | 0603 | C22775 | UNI-ROYAL | 0603WAF1000T5E | 6
R2 | 10K 1% 1/10W | 0603 | C25804 | UNI-ROYAL | 0603WAF1002T5E | 6
R3 | 3K3 1% 1/10W (substitute MPN OK) | 0603 | C22978 | UNI-ROYAL | 0603WAF3301T5E | 6

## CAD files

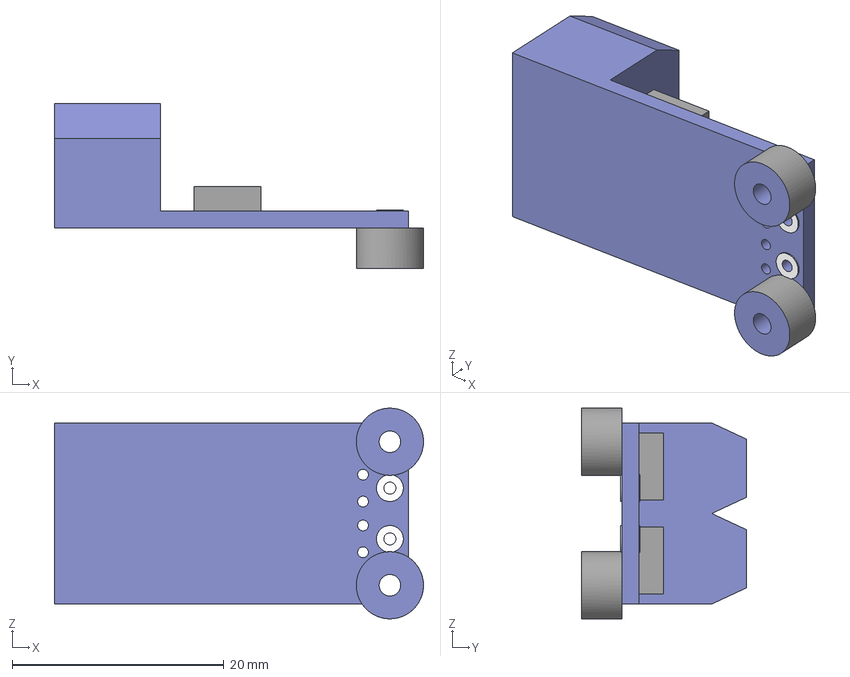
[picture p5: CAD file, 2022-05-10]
lta-power-module/3d models/Dual MOSFET Driver.step
34.9 x 15.6 x 19.9 mm

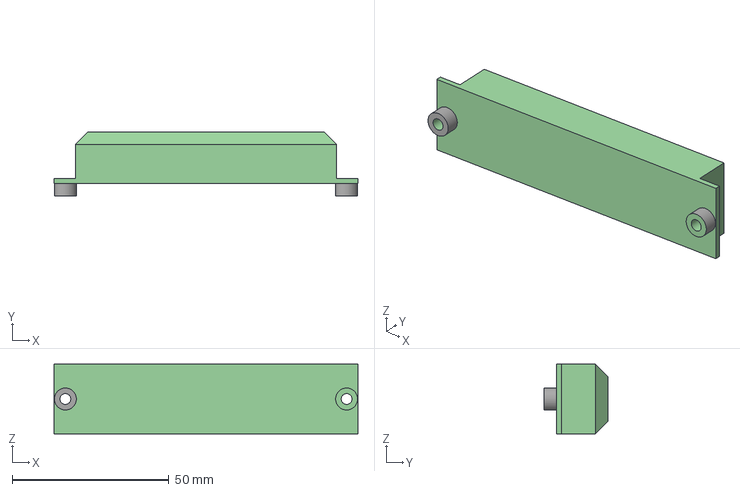
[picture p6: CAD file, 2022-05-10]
lta-power-module/3d models/12-way power distribution bus pcb.step
96.9 x 20.4 x 22.2 mm

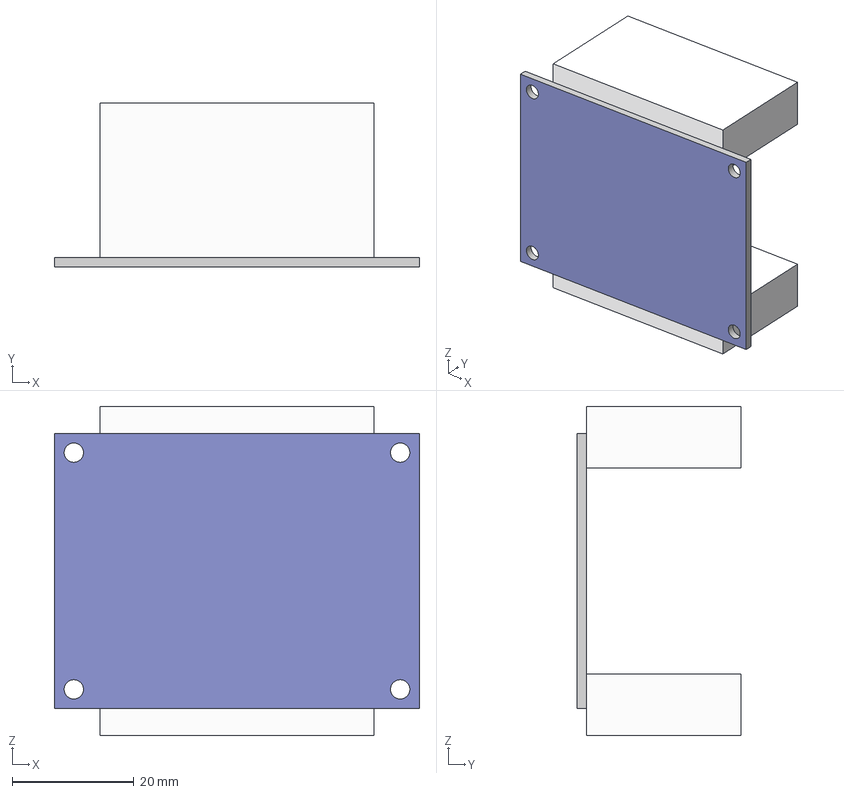
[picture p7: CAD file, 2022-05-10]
lta-power-module/3d models/12V regulator.step
60.0 x 27.0 x 54.2 mm

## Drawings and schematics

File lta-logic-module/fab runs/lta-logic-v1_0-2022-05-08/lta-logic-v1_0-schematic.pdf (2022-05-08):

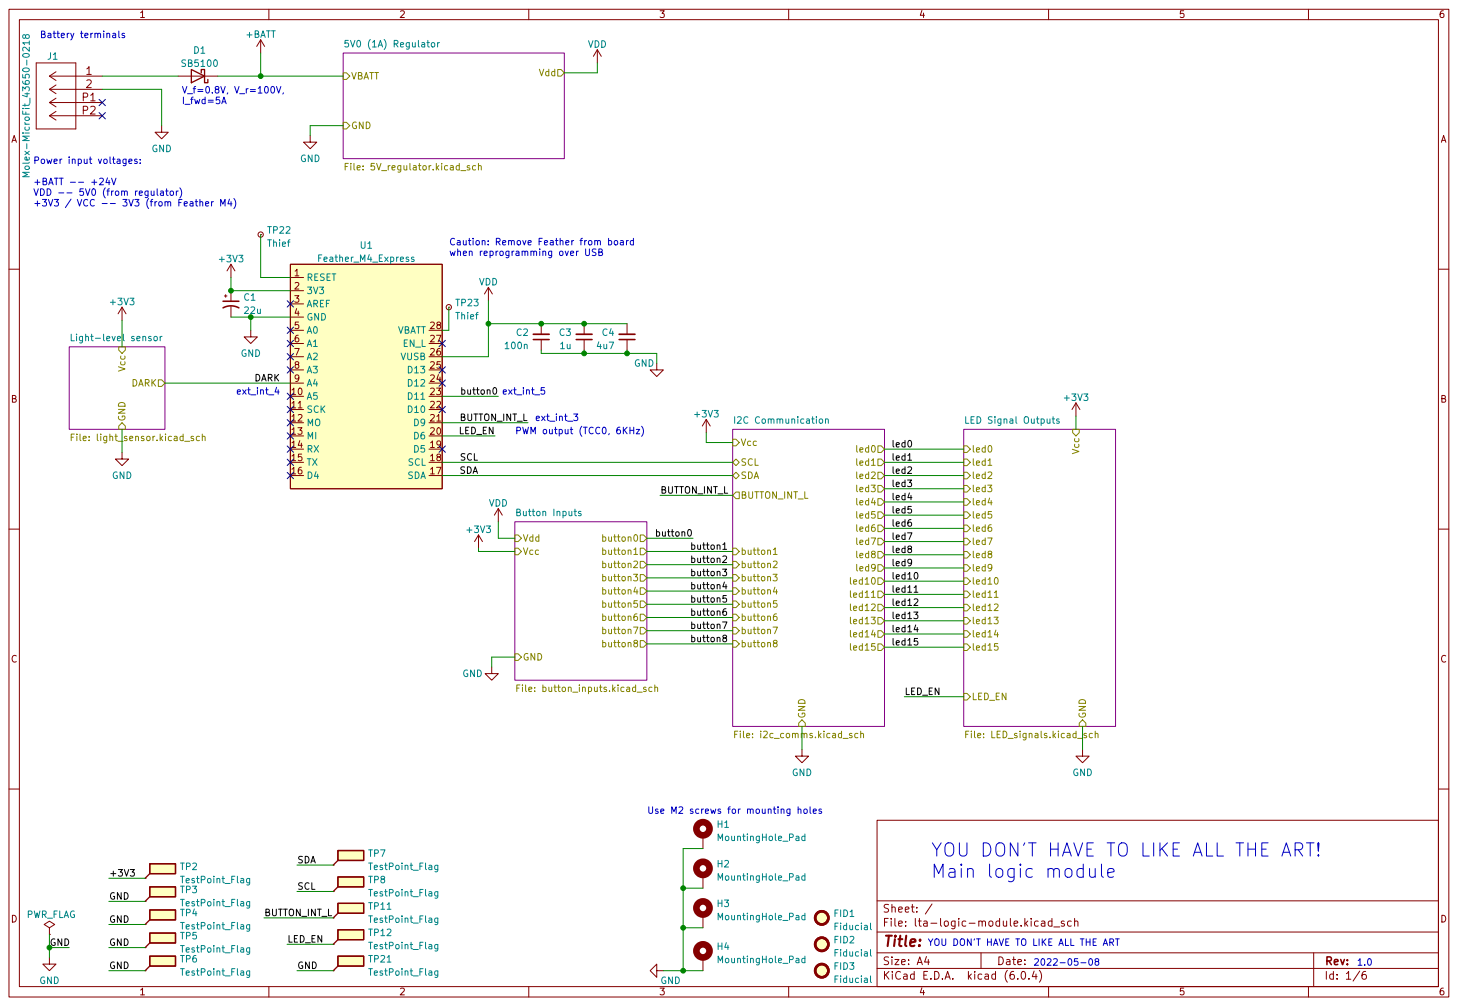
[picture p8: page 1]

Power input voltages: +BATT -- +24V

File: button_inputs.kicad_sch GND Vcc DARK

Vdd Vcc Button Inputs

button4 | led11
button5 | led12
button6 | led13

Use M2 screws for mounting holes

YOU DON'T HAVE TO LIKE ALL THE ART!
Main logic module
FID2 Fiducial FID1 Fiducial FID3 Fiducial

File: lta-logic-module.kicad_sch Sheet: /
Id: 1/6 Title:

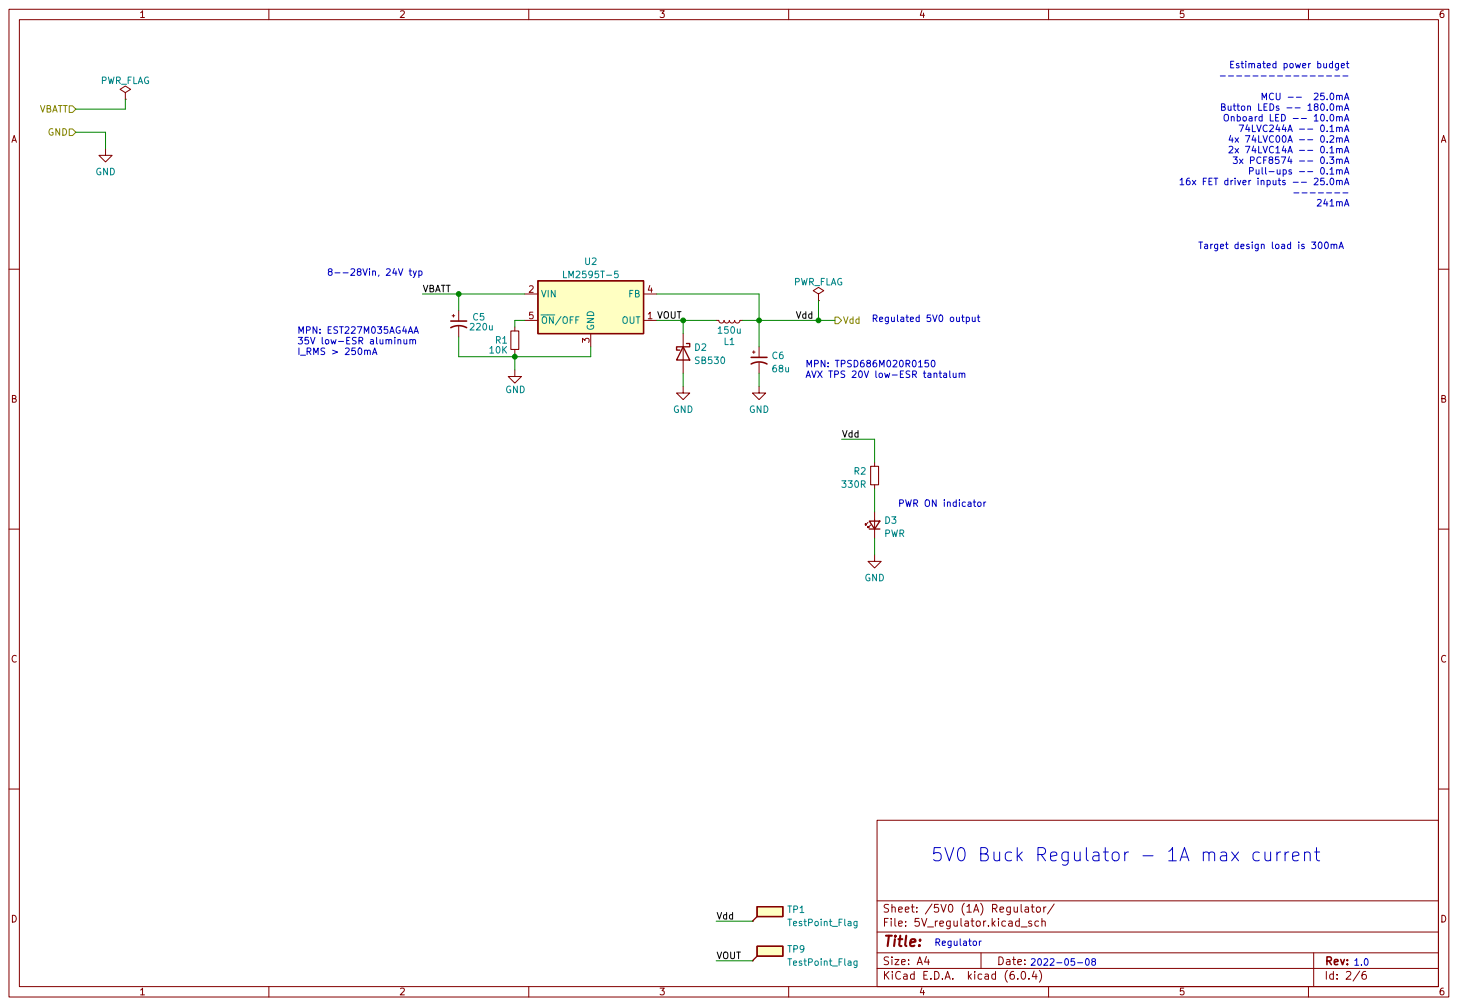
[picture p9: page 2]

Button LEDs -- 180.0mA Onboard LED -- 10.0mA

Target design load is 300mA MPN: EST227M035AG4AA

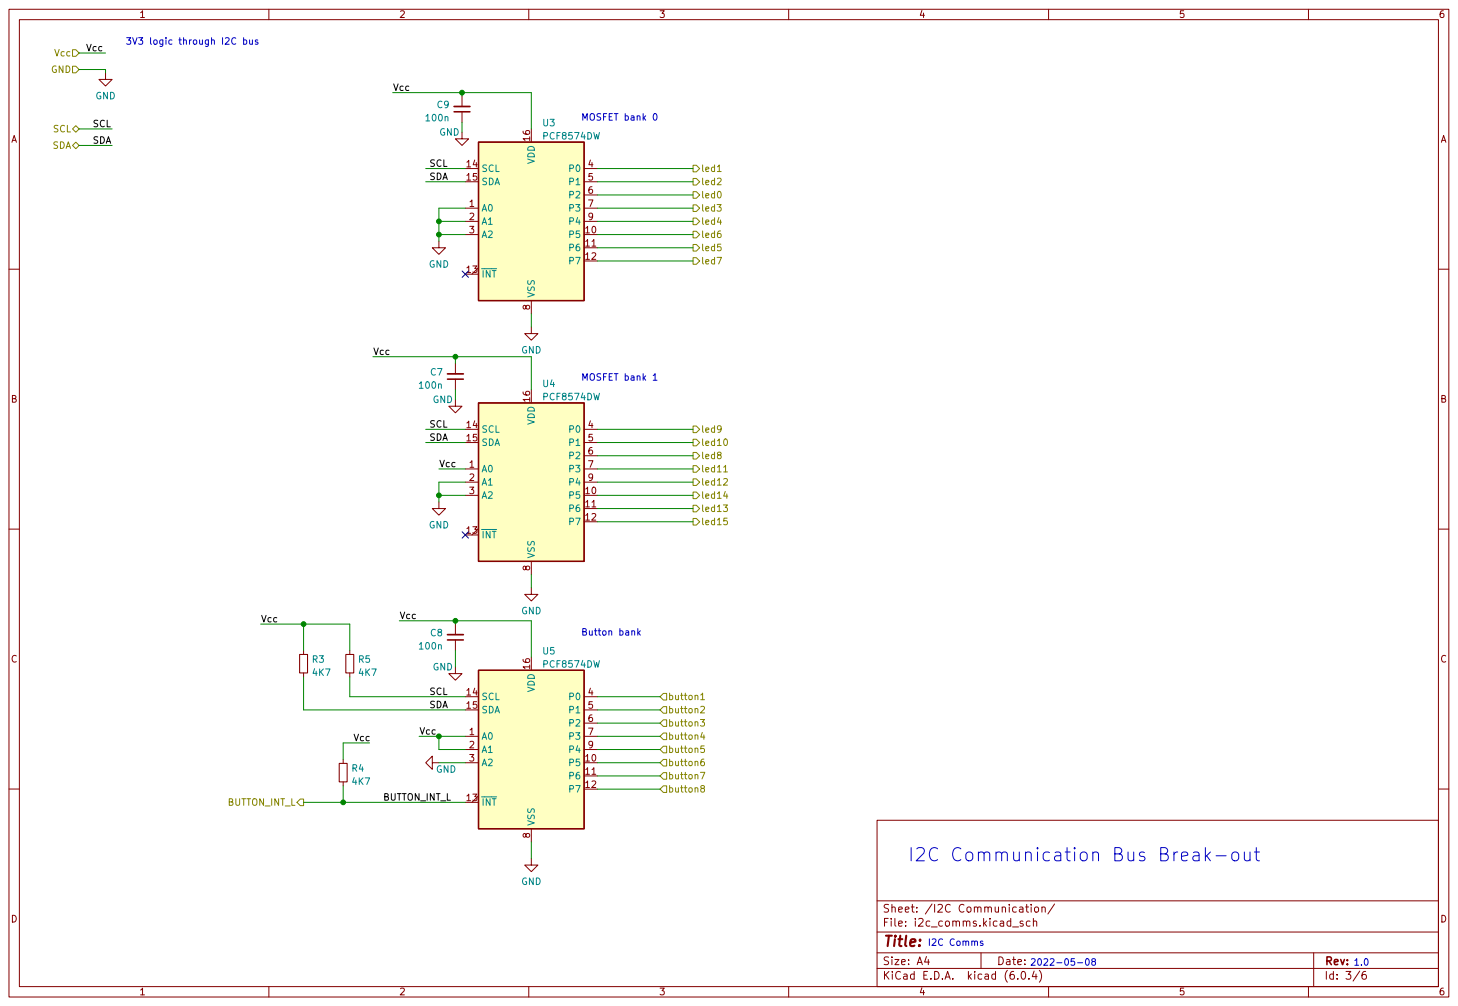
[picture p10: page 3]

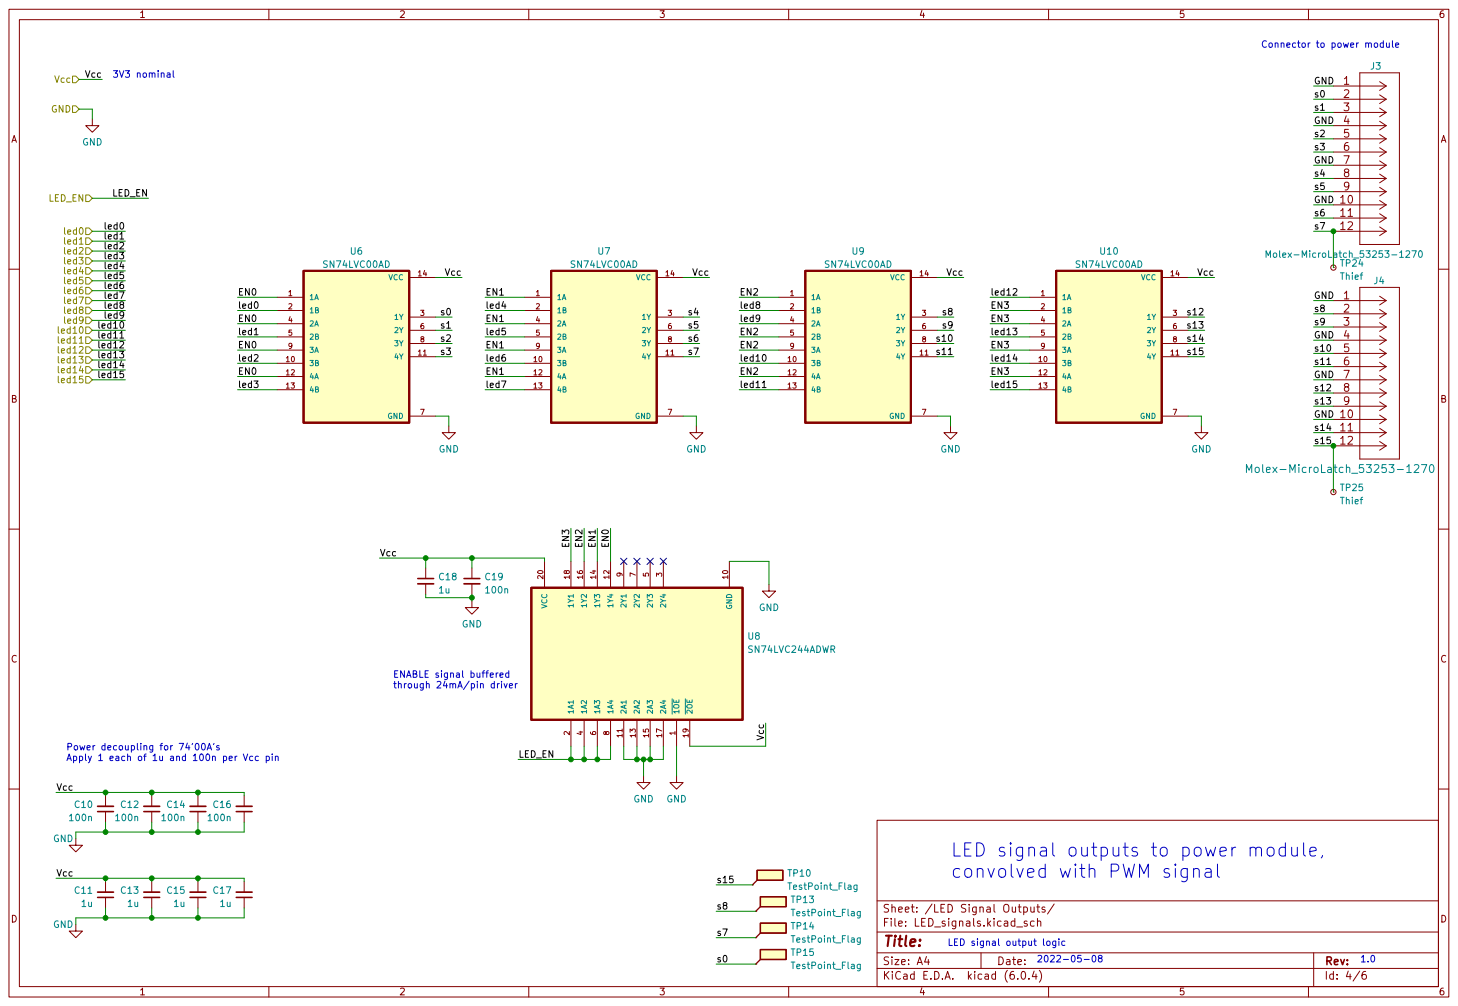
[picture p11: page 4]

Connector to power module

Power decoupling for 74'00A's
Apply 1 each of 1u and 100n per Vcc pin

Sheet: /LED Signal Outputs/ C13

LED signal output logic

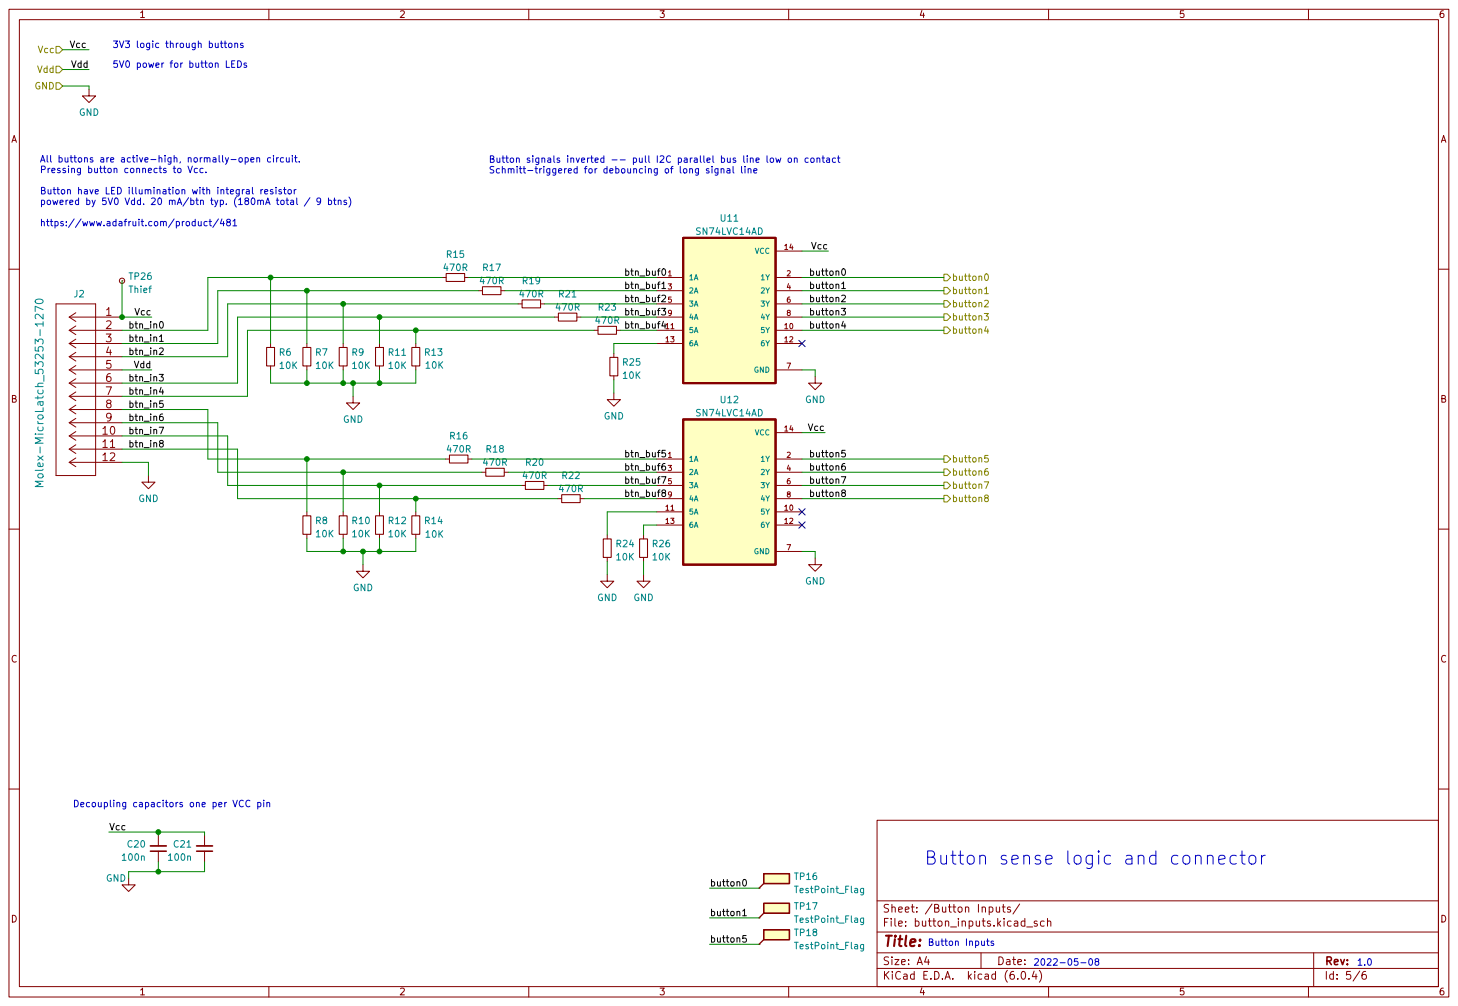
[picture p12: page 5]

3V3 logic through buttons
5V0 power for button LEDs

All buttons are active-high, normally-open circuit.
Pressing button connects to Vcc.

Button signals inverted -- pull I2C parallel bus line low on contact
Schmitt-triggered for debouncing of long signal line

Button have LED illumination with integral resistor
powered by 5V0 Vdd. 20 mA/btn typ. (180mA total / 9 btns)

https://www.adafruit.com/product/481

Button sense logic and connector

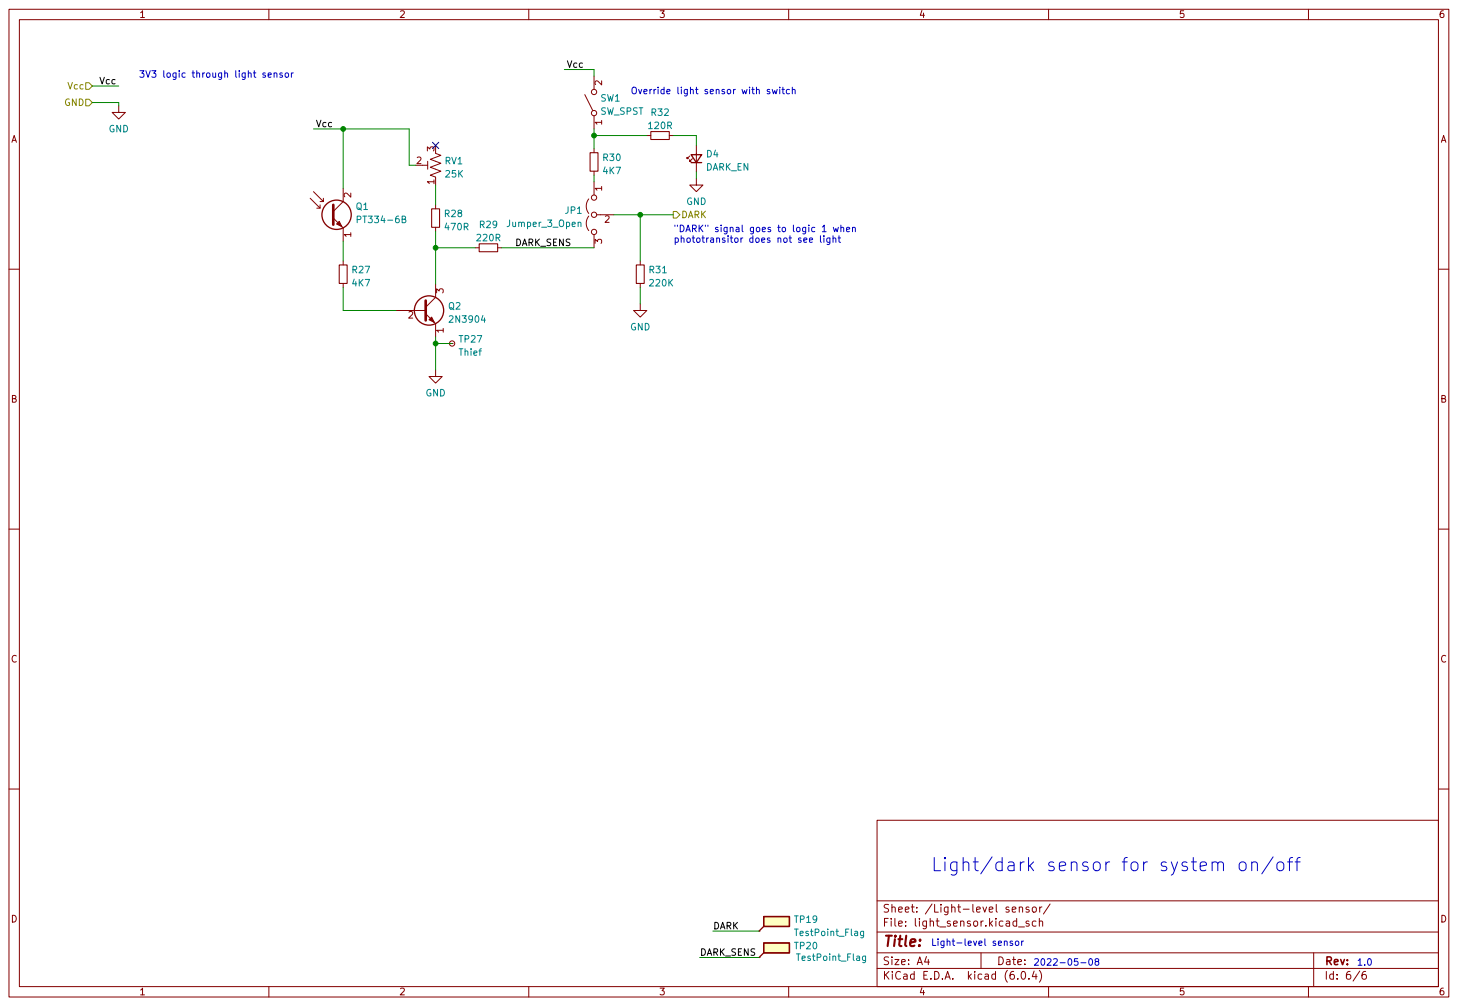
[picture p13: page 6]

3V3 logic through light sensor

Override light sensor with switch

"DARK" signal goes to logic 1 when
phototransitor does not see light

Light/dark sensor for system on/off

Sheet: /Light-level sensor/
File: light_sensor.kicad_sch
Id: 6/6 Title:

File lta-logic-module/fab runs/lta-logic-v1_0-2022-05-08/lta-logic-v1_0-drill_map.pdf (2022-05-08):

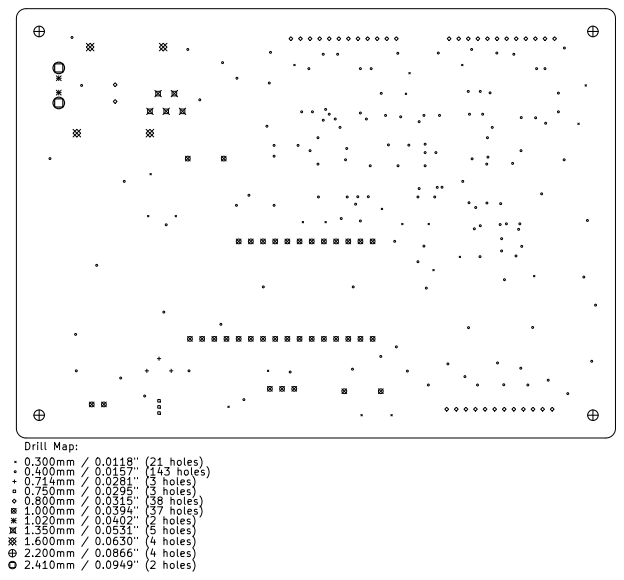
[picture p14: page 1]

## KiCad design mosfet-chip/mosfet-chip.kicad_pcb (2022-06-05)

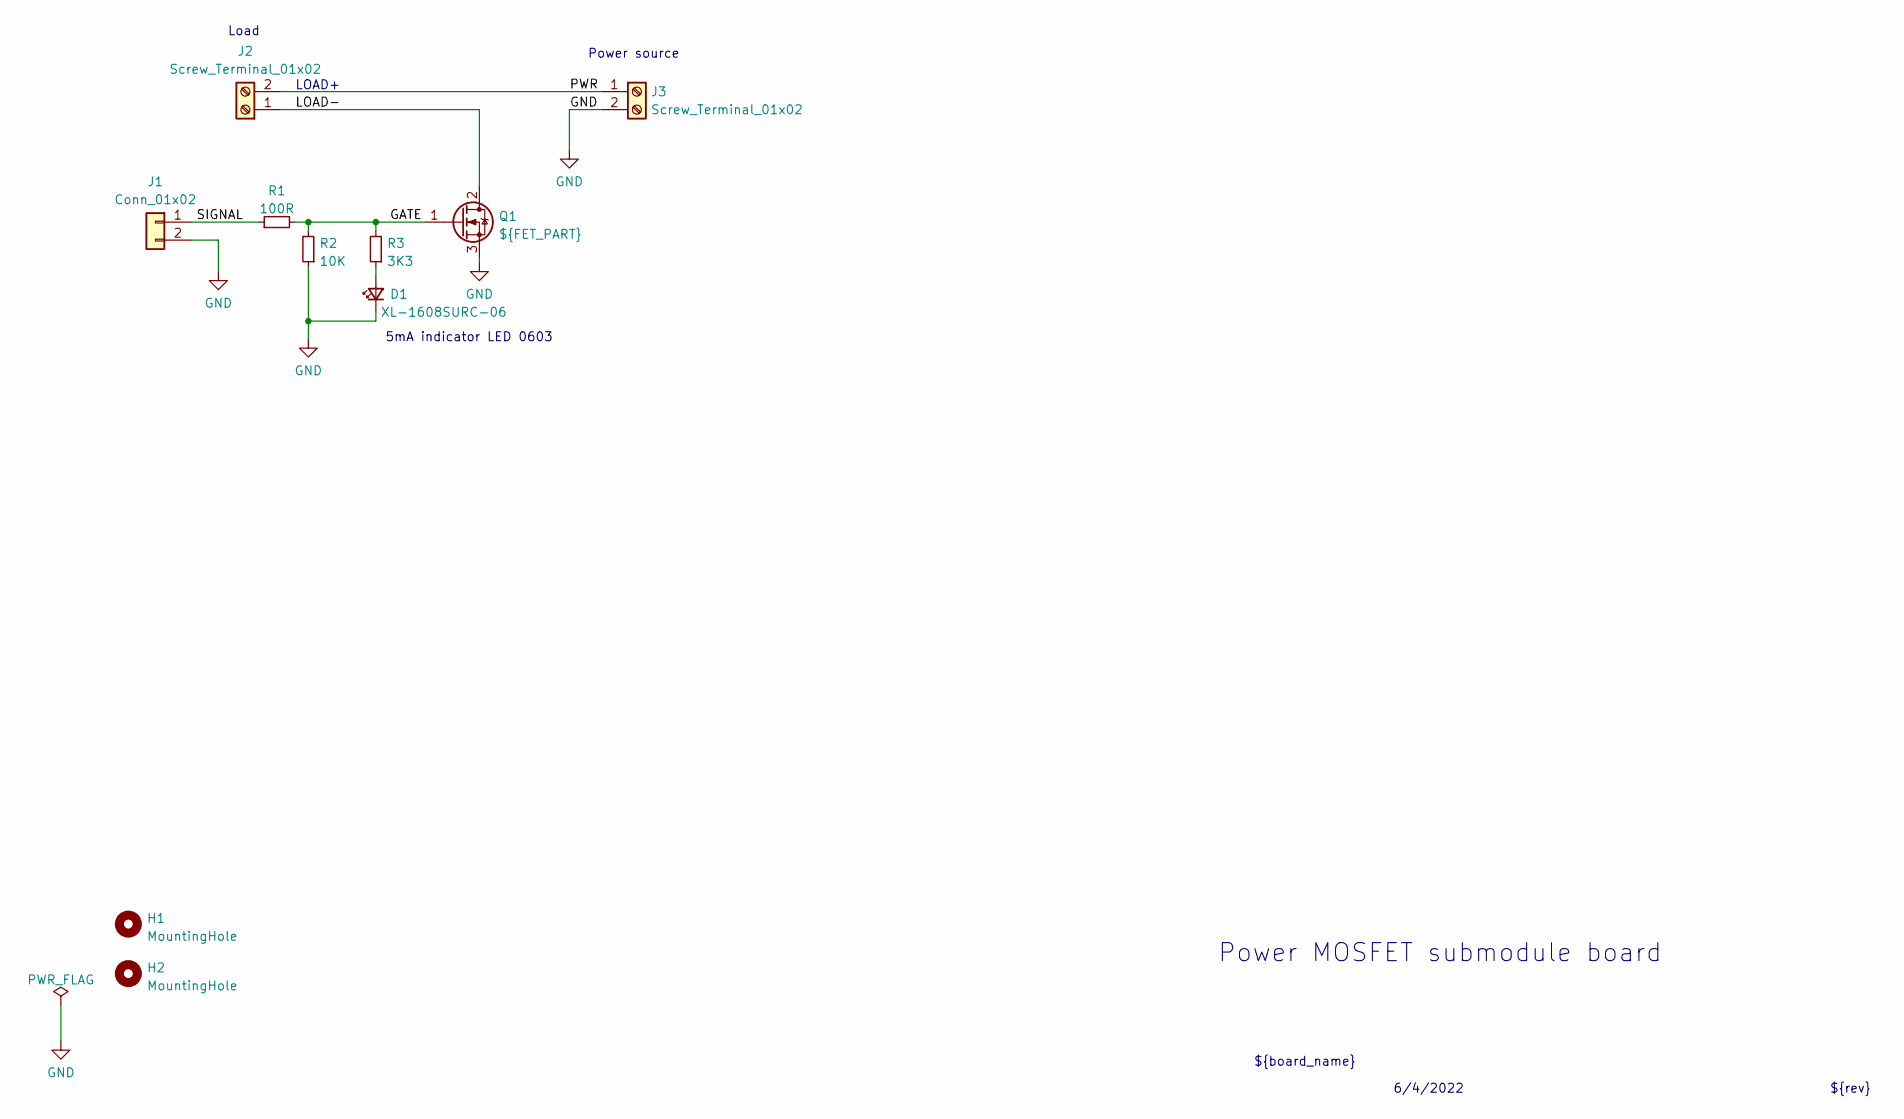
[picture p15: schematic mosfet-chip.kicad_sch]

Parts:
D1: XL-1608SURC-06; LED_0603_1608Metric; MPN XL-1608SURC-06; JLCPCB_PN C965799
H1, H2: MountingHole; MountingHole_80mil
J1: Conn_01x02; PinHeader_1x02_P2.54mm_Vertical; MPN 5-146858-1; JLCPCB_PN DNP
J2, J3: Screw_Terminal_01x02; Phoenix_1x02_1711725; MPN 1711725; JLCPCB_PN C89120
Q1: ${FET_PART}; TO-220-3_Vertical; MPN IRLZ34NPbF; JLCPCB_PN C513144
R1: 100R; R_0603_1608Metric; MPN 0603WAF1000T5E; JLCPCB_PN C22775
R2: 10K; R_0603_1608Metric; MPN 0603WAF1002T5E; JLCPCB_PN C25804
R3: 3K3; R_0603_1608Metric; MPN 0603WAF3301T5E; JLCPCB_PN C22978

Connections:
/GATE: Q1.1 (G), R1.2, R2.2, R3.2
/LOAD-: J2.1, Q1.2 (D)
/PWR: J2.2, J3.1
/SIGNAL: J1.1, R1.1
GND: D1.1 (K), J1.2, J3.2, Q1.3 (S), R2.1
unnamed: D1.2 (A), R3.1

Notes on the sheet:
Load
Power MOSFET submodule board
5mA indicator LED 0603
${rev}
LOAD+
${board_name}
6/4/2022
Power source

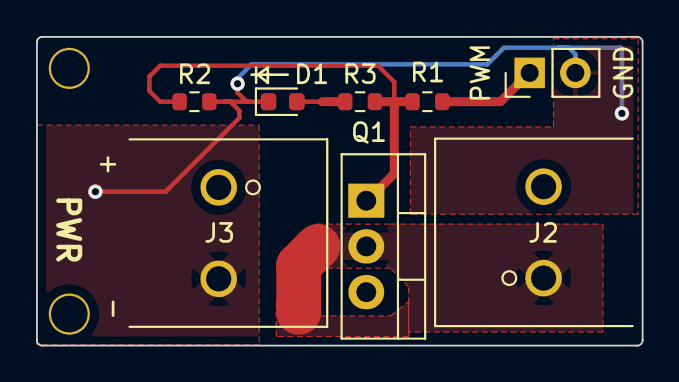
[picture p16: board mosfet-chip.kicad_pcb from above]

Board: 2 copper layers, 33.6 x 17.1 mm, 10 parts (0 on the bottom side), 6 nets.

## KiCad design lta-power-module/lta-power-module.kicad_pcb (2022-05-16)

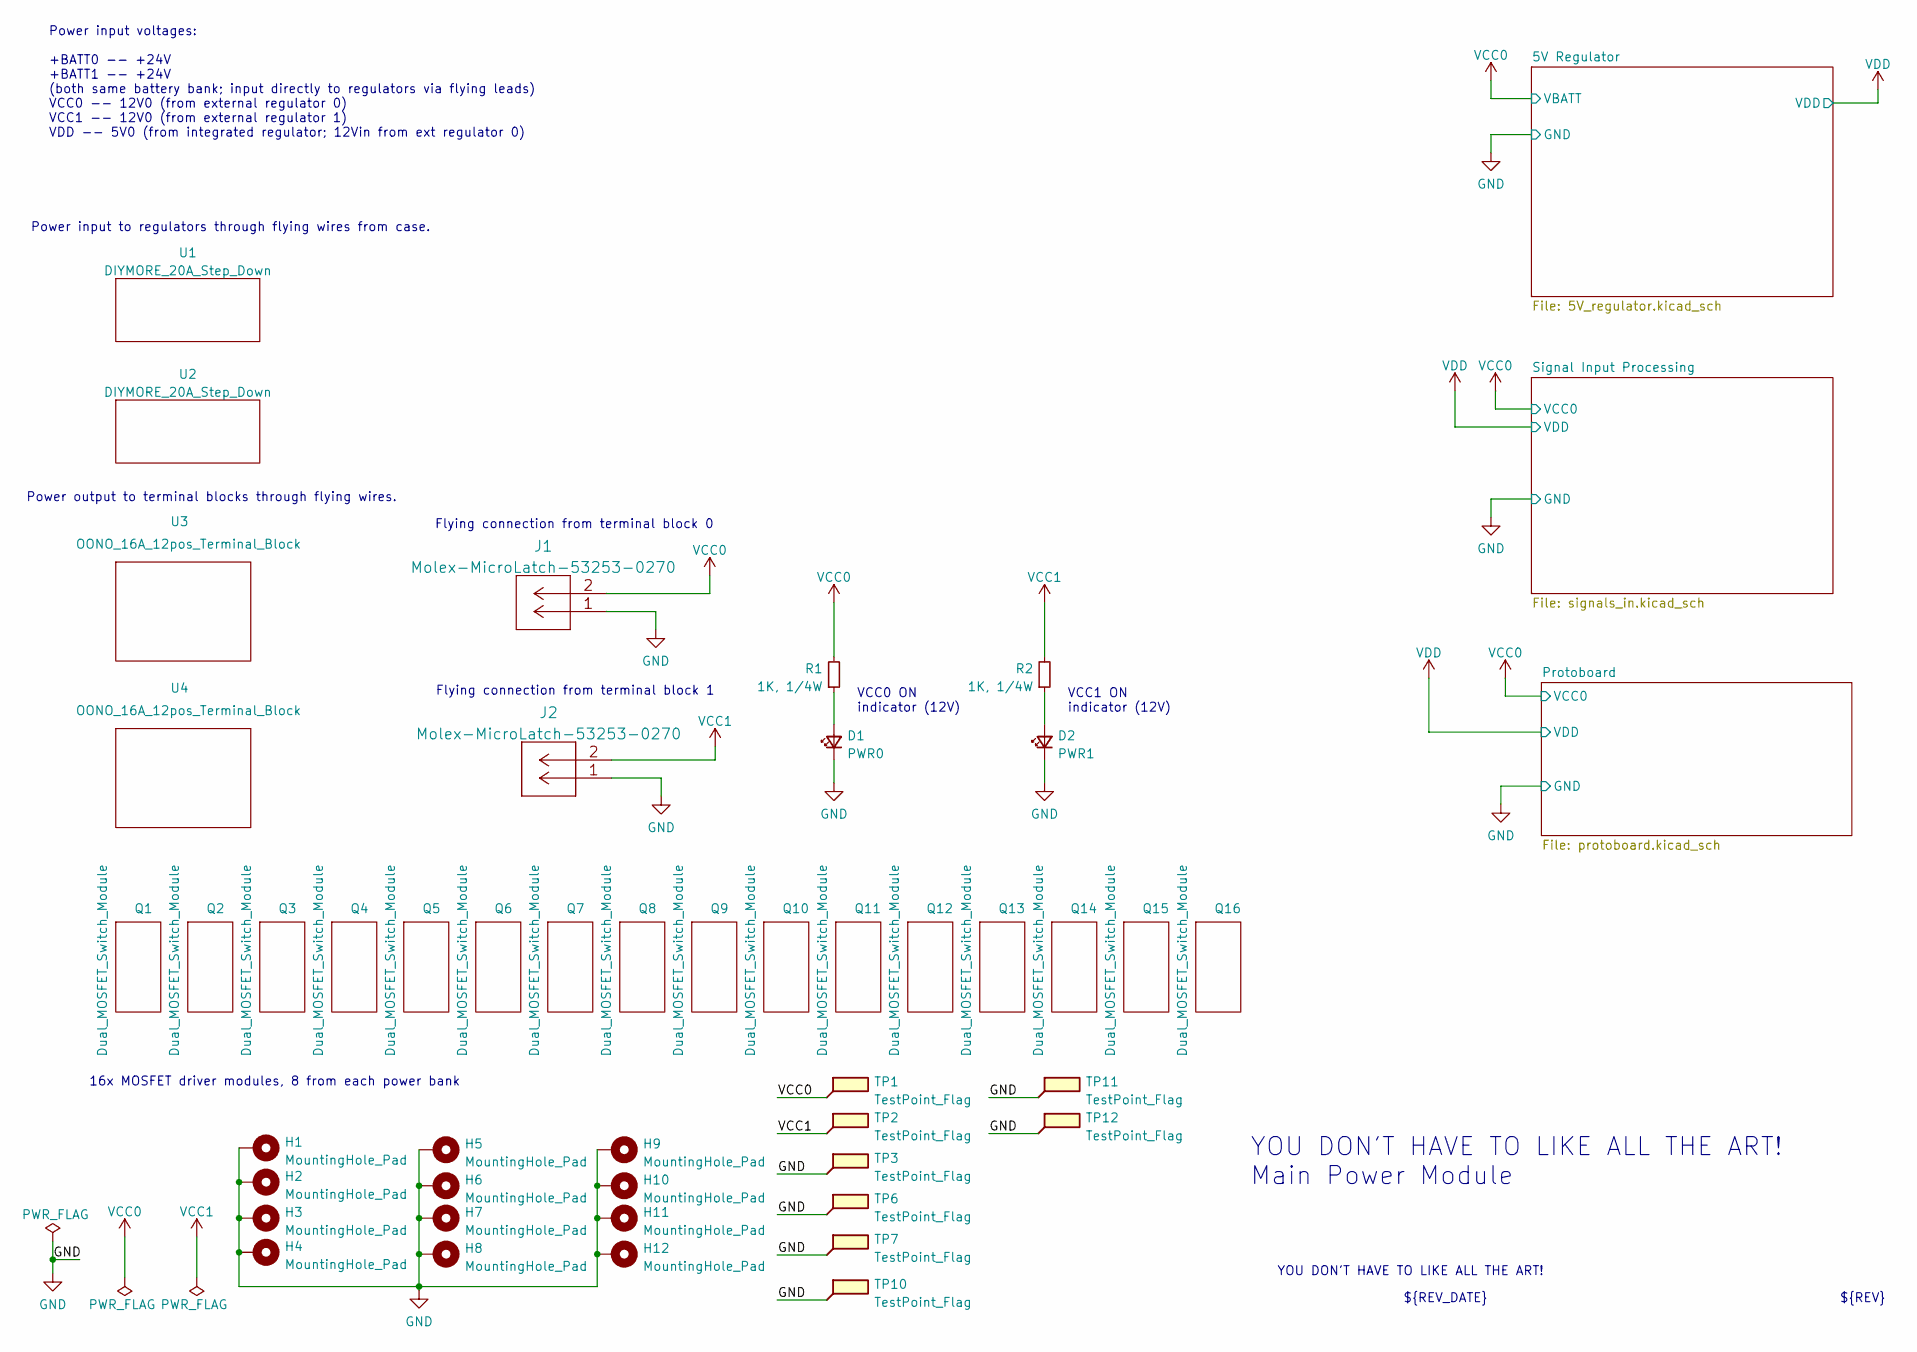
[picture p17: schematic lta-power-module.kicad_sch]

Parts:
D1: PWR0; LED_D5.0mm_SilkFix; MPN C5SMF-RJF-CT0W0BB1
D2: PWR1; LED_D5.0mm_SilkFix; MPN C5SMF-RJF-CT0W0BB1
H1, H2, H3, H4, H5, H6, H7, H8, H9, H10, H11, H12: MountingHole_Pad; MountingHole_5.3mm_M5_ISO7380_Pad
J1, J2: Molex-MicroLatch-53253-0270; MPN 532530270
Q1, Q2, Q3, Q4, Q5, Q6, Q7, Q8, Q9, Q10, Q11, Q12, Q13, Q14, Q15, Q16: Dual_MOSFET_Switch_Module; Dual_MOSFET_Driver
R1, R2: 1K, 1/4W; R_Axial_DIN0207_L6.3mm_D2.5mm_P7.62mm_Horizontal; MPN CF14JT1K00
TP1, TP2, TP3, TP6, TP7, TP10, TP11, TP12: TestPoint_Flag; TestPoint_THTPad_1.0x1.0mm_Drill0.3mm
U1, U2: DIYMORE_20A_Step_Down; 12V_regulator
U3, U4: OONO_16A_12pos_Terminal_Block; 12-way_power_distribution_bus

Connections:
GND: D1.1 (K), D2.1 (K), H1.1, H2.1, H3.1, H4.1, H5.1, H6.1, H7.1, H8.1, H9.1, H10.1, H11.1, H12.1, J1.1, J2.1, TP3.1, TP6.1, TP7.1, TP10.1, TP11.1, TP12.1; also elsewhere on the board
unnamed: D1.2 (A), R1.1
unnamed: D2.2 (A), R2.1
VCC0: J1.2, R1.2, TP1.1; also elsewhere on the board
VCC1: J2.2, R2.2, TP2.1

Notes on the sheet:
${REV}
VCC1 ON indicator (12V)
Flying connection from terminal block 0
Power output to terminal blocks through flying wires.
Power input to regulators through flying wires from case.
YOU DON'T HAVE TO LIKE ALL THE ART!
YOU DON'T HAVE TO LIKE ALL THE ART! Main Power Module
16x MOSFET driver modules, 8 from each power bank
VCC0 ON indicator (12V)
Power input voltages: +BATT0 -- +24V +BATT1 -- +24V (both same battery bank; input directly to regulators via flying leads) VCC0 -- 12V0 (from external regulator 0) VCC1 -- 12V0 (from external regulator 1) VDD -- 5V0 (from integrated regulator; 12Vin from ext regulator 0)
Flying connection from terminal block 1
${REV_DATE}

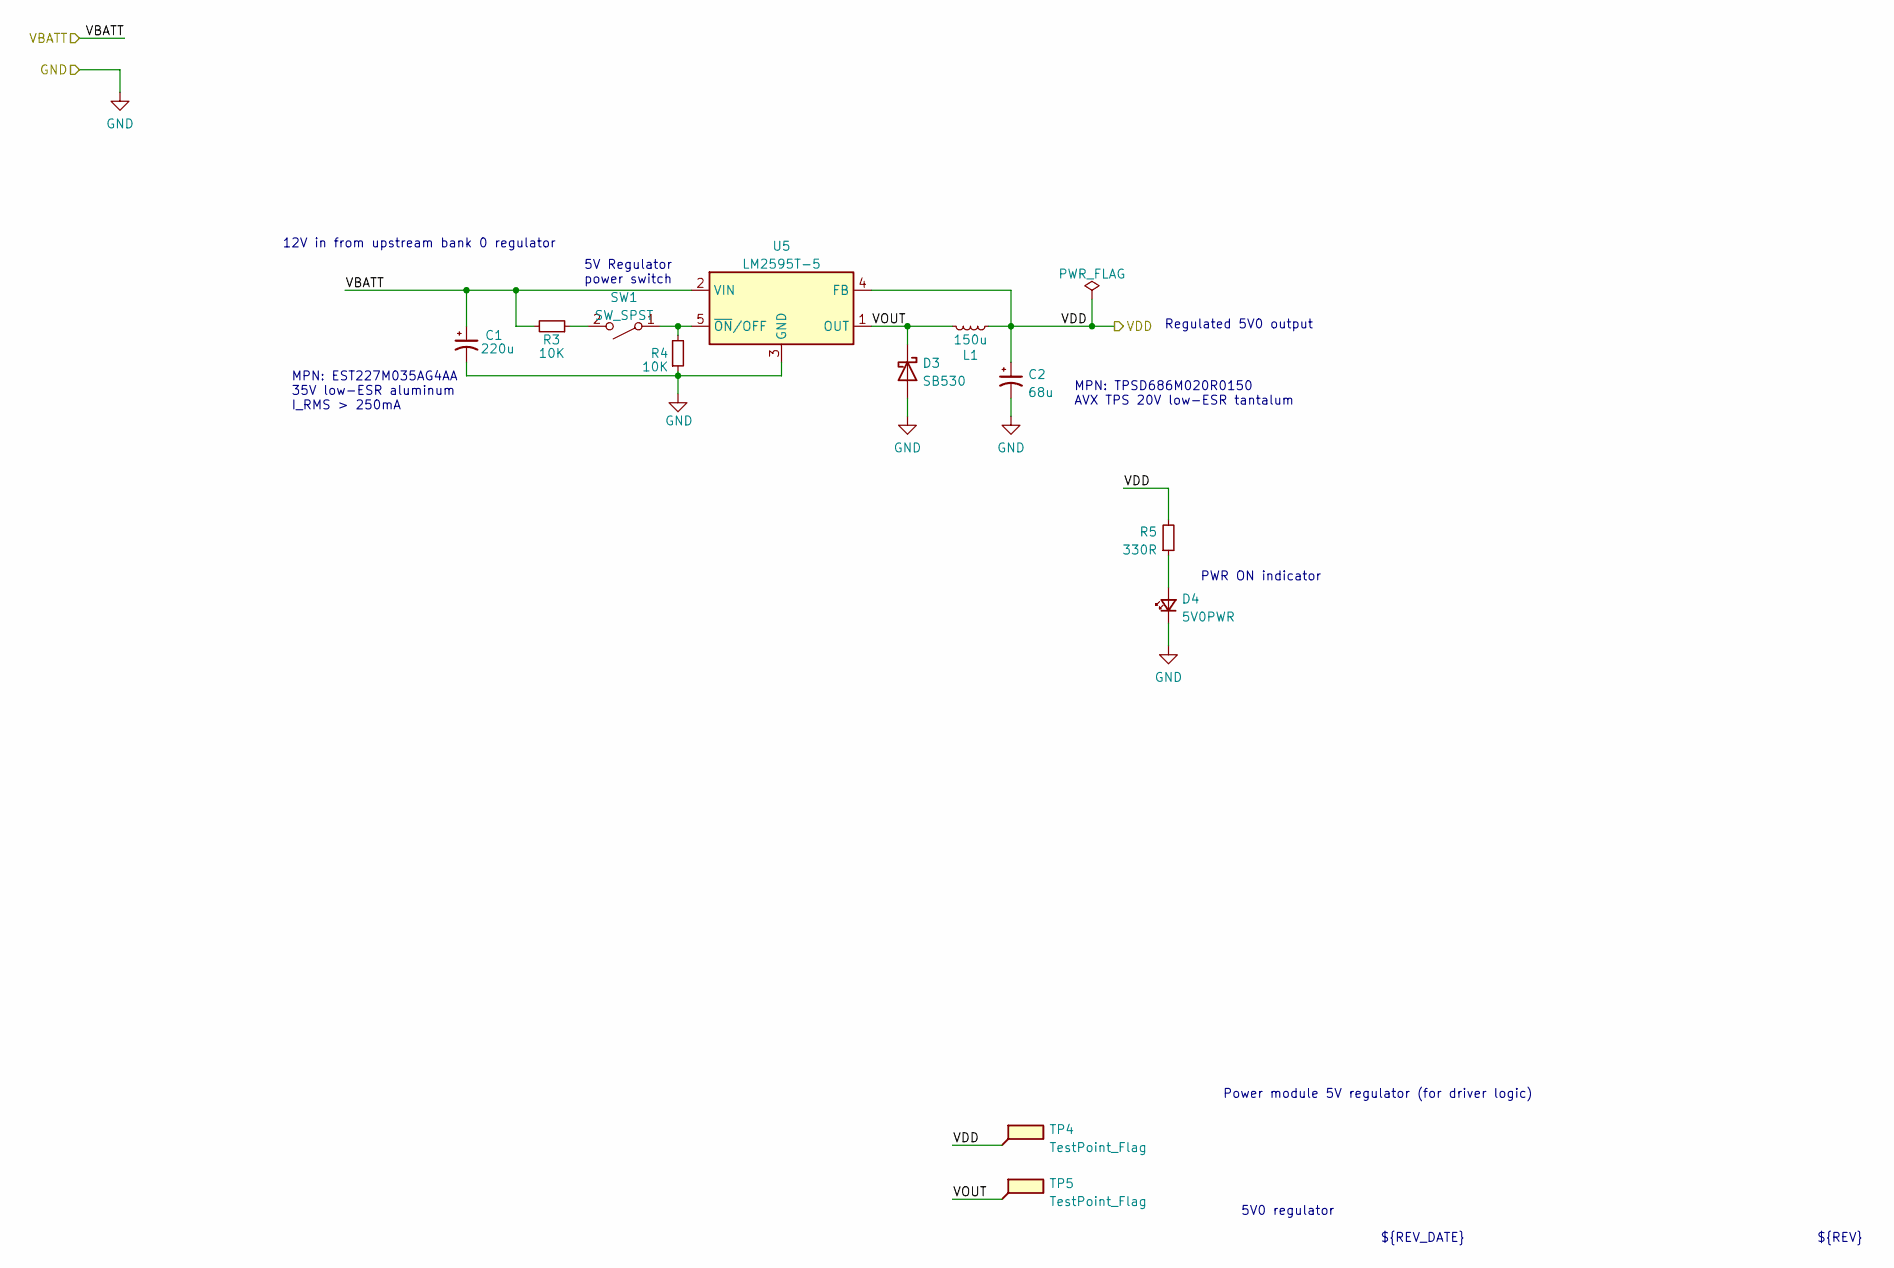
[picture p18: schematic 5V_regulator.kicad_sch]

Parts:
C1: 220u; CP_Radial_D8.0mm_P3.50mm; MPN EST227M035AG4AA
C2: 68u; CP_EIA-7343-30_AVX-N_Pad2.25x2.55mm_HandSolder; MPN TPSD686M020R0150
D3: SB530; D_DO-201AD_P15.24mm_Horizontal; MPN SB530-E3/54
D4: 5V0PWR; LED_D5.0mm_SilkFix; MPN C5SMF-RJF-CT0W0BB1
L1: 150u; L_Radial_D13.5mm_P7.50mm; MPN AIUR-06-151K
R3, R4: 10K; R_Axial_DIN0204_L3.6mm_D1.6mm_P5.08mm_Horizontal; MPN CF18JT10K0
R5: 330R; R_Axial_DIN0204_L3.6mm_D1.6mm_P5.08mm_Horizontal; MPN CF18JT330R
SW1: SW_SPST; CUI-DIP-SW_DS01-254-x-01xx; MPN DS01-254-S-01BE
TP4, TP5: TestPoint_Flag; TestPoint_THTPad_1.0x1.0mm_Drill0.3mm
U5: LM2595T-5; TO-220-5_P3.4x3.7mm_StaggerOdd_Lead3.8mm_Vertical-SilkFix; MPN LM2595T-5.0/NOPB

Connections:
/5V Regulator/VOUT: D3.1 (K), L1.2, TP5.1, U5.1 (OUT)
GND: C1.2, C2.2, D3.2 (A), D4.1 (K), R4.1, U5.3 (GND); also elsewhere on the board
unnamed: D4.2 (A), R5.1
unnamed: R3.1, SW1.2 (B)
unnamed: R4.2, SW1.1 (A), U5.5 (~ON/OFF)
VCC0: C1.1, R3.2, U5.2 (VIN); also elsewhere on the board
VDD: C2.1, L1.1, R5.2, TP4.1, U5.4 (FB); also elsewhere on the board

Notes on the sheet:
MPN: TPSD686M020R0150 AVX TPS 20V low-ESR tantalum
12V in from upstream bank 0 regulator
Power module 5V regulator (for driver logic)
MPN: EST227M035AG4AA 35V low-ESR aluminum I_RMS > 250mA
${REV}
Regulated 5V0 output
5V0 regulator
5V Regulator power switch
${REV_DATE}
PWR ON indicator

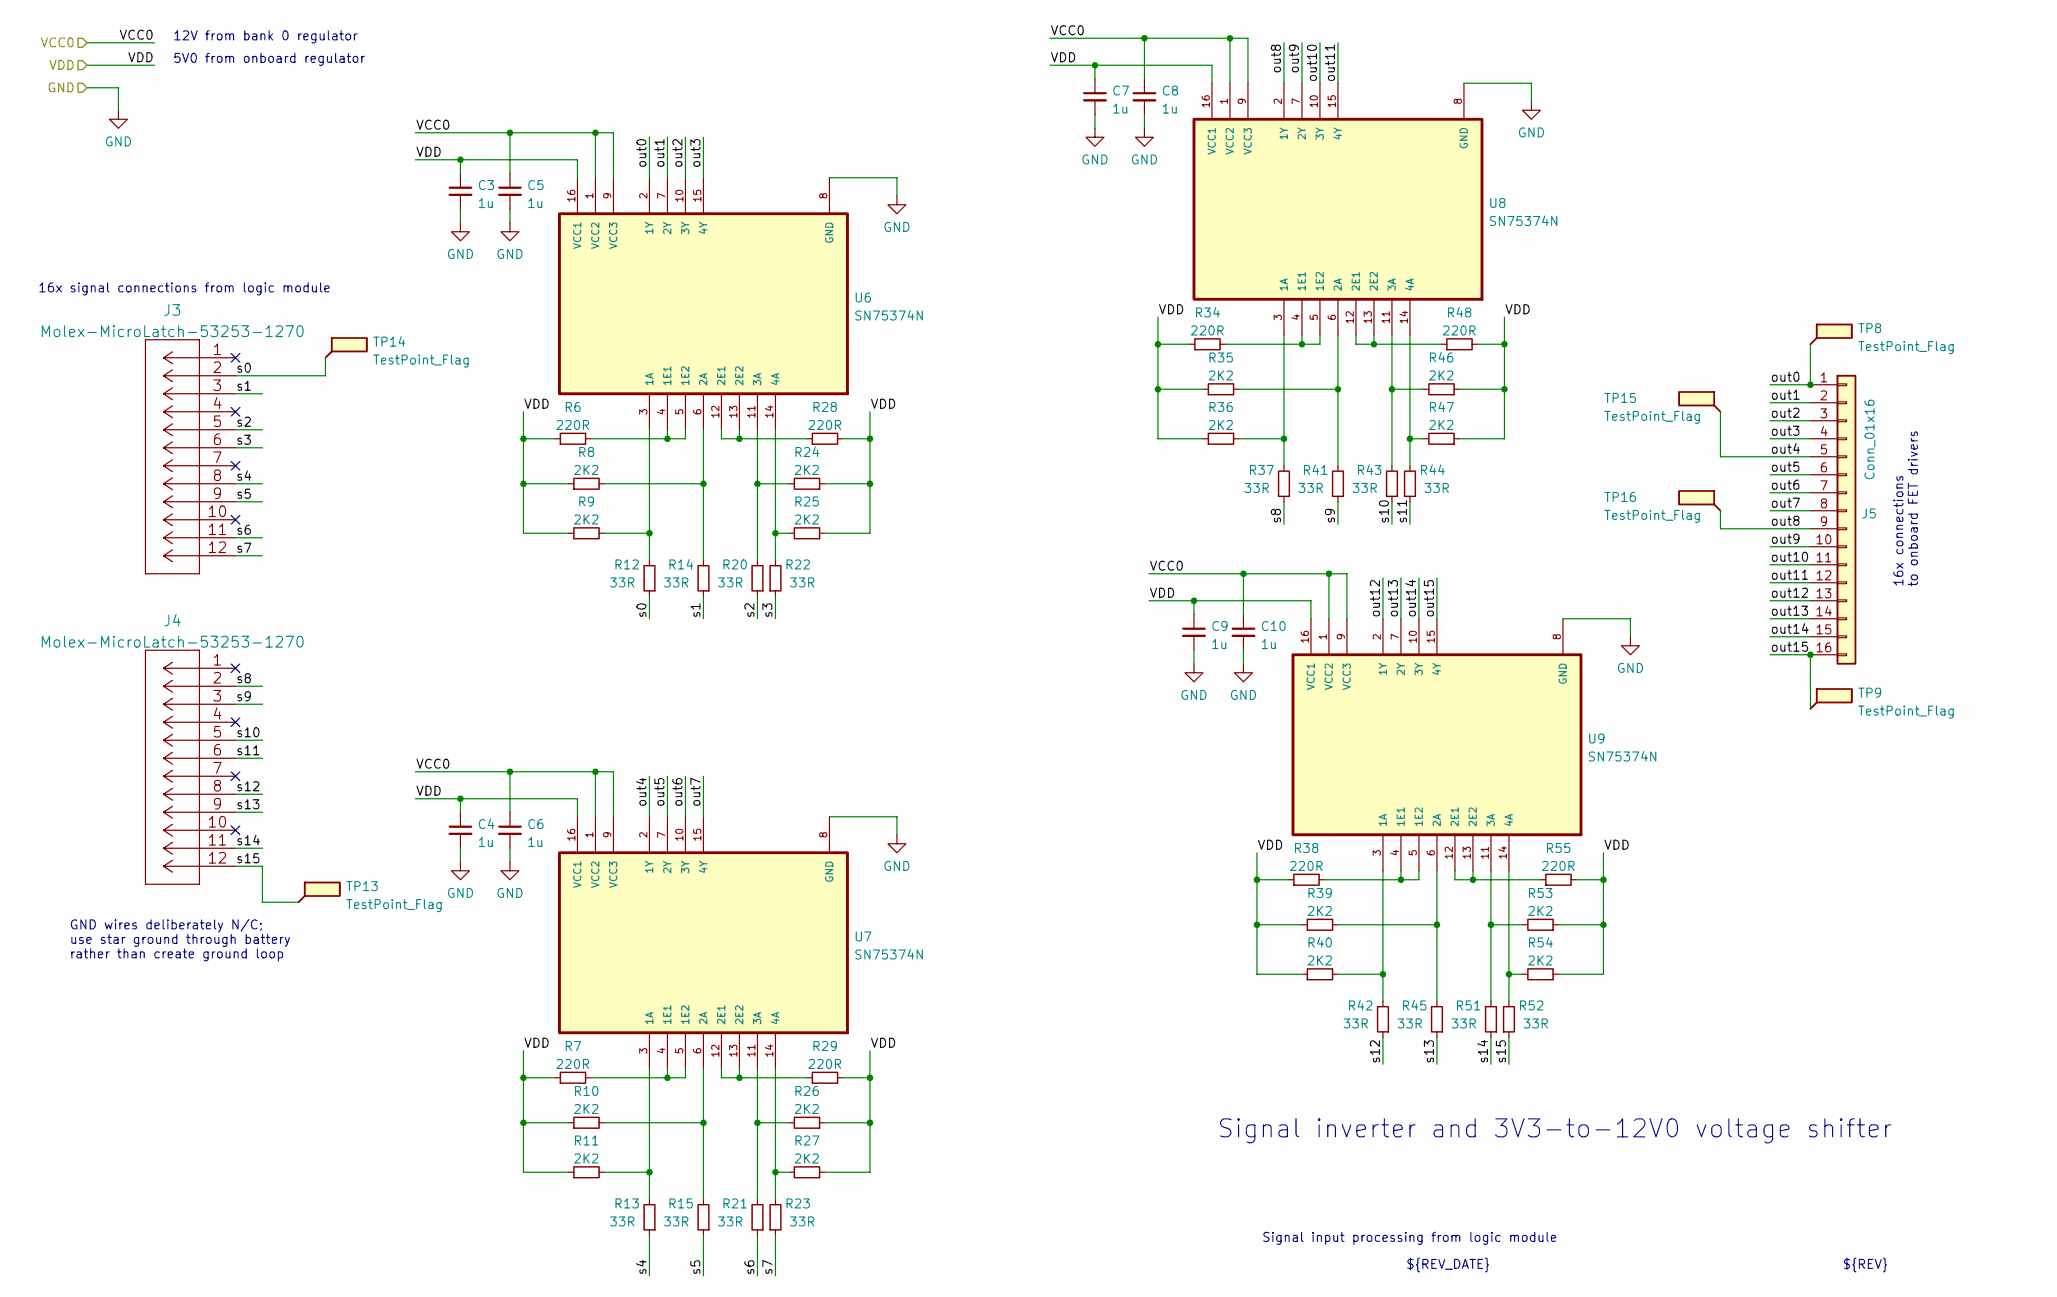
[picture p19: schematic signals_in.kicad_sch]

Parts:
C3, C4, C5, C6, C7, C8, C9, C10: 1u; C_Disc_D3.8mm_W2.6mm_P2.50mm; MPN C315C105K3R5TA7303
J3, J4: Molex-MicroLatch-53253-1270; MPN 532531270
J5: Conn_01x16; PinHeader_1x16_P2.54mm_Vertical; MPN 5-146858-1
R6, R7, R28, R29, R34, R38, R48, R55: 220R; R_Axial_DIN0204_L3.6mm_D1.6mm_P5.08mm_Horizontal; MPN CF18JT220R
R8, R9, R10, R11, R24, R25, R26, R27, R35, R36, R39, R40, R46, R47, R53, R54: 2K2; R_Axial_DIN0204_L3.6mm_D1.6mm_P5.08mm_Horizontal; MPN CF18JT2K20
R12, R13, R14, R15, R20, R21, R22, R23, R37, R41, R42, R43, R44, R45, R51, R52: 33R; R_Axial_DIN0204_L3.6mm_D1.6mm_P5.08mm_Horizontal; MPN CF18JT33R0
TP8, TP9, TP13, TP14, TP15, TP16: TestPoint_Flag; TestPoint_THTPad_1.0x1.0mm_Drill0.3mm
U6, U7, U8, U9: SN75374N; TI_N_R-PDIP-T16; MPN SN75374N

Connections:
/Signal Input Processing/out0: J5.1, TP8.1, U6.2 (1Y)
/Signal Input Processing/out1: J5.2, U6.7 (2Y)
/Signal Input Processing/out2: J5.3, U6.10 (3Y)
/Signal Input Processing/out3: J5.4, U6.15 (4Y)
/Signal Input Processing/out4: J5.5, TP15.1, U7.2 (1Y)
/Signal Input Processing/out5: J5.6, U7.7 (2Y)
/Signal Input Processing/out6: J5.7, U7.10 (3Y)
/Signal Input Processing/out7: J5.8, U7.15 (4Y)
/Signal Input Processing/out8: J5.9, TP16.1, U8.2 (1Y)
/Signal Input Processing/out9: J5.10, U8.7 (2Y)
/Signal Input Processing/out10: J5.11, U8.10 (3Y)
/Signal Input Processing/out11: J5.12, U8.15 (4Y)
/Signal Input Processing/out12: J5.13, U9.2 (1Y)
/Signal Input Processing/out13: J5.14, U9.7 (2Y)
/Signal Input Processing/out14: J5.15, U9.10 (3Y)
/Signal Input Processing/out15: J5.16, TP9.1, U9.15 (4Y)
/Signal Input Processing/s0: J3.2, R12.1, TP14.1
/Signal Input Processing/s1: J3.3, R14.1
/Signal Input Processing/s2: J3.5, R20.1
/Signal Input Processing/s3: J3.6, R22.1
/Signal Input Processing/s4: J3.8, R13.1
/Signal Input Processing/s5: J3.9, R15.1
/Signal Input Processing/s6: J3.11, R21.1
/Signal Input Processing/s7: J3.12, R23.1
/Signal Input Processing/s8: J4.2, R37.1
/Signal Input Processing/s9: J4.3, R41.1
/Signal Input Processing/s10: J4.5, R43.1
/Signal Input Processing/s11: J4.6, R44.1
/Signal Input Processing/s12: J4.8, R42.1
/Signal Input Processing/s13: J4.9, R45.1
/Signal Input Processing/s14: J4.11, R51.1
/Signal Input Processing/s15: J4.12, R52.1, TP13.1
GND: C3.2, C4.2, C5.2, C6.2, C7.2, C8.2, C9.2, C10.2, U6.8 (GND), U7.8 (GND), U8.8 (GND), U9.8 (GND); also elsewhere on the board
unnamed: R6.2, U6.4 (1E1), U6.5 (1E2)
unnamed: R7.2, U7.4 (1E1), U7.5 (1E2)
unnamed: R10.2, R15.2, U7.6 (2A)
unnamed: R11.2, R13.2, U7.3 (1A)
unnamed: R9.2, R12.2, U6.3 (1A)
unnamed: R8.2, R14.2, U6.6 (2A)
unnamed: R20.2, R24.2, U6.11 (3A)
unnamed: R21.2, R26.2, U7.11 (3A)
unnamed: R22.2, R25.2, U6.14 (4A)
unnamed: R23.2, R27.2, U7.14 (4A)
unnamed: R28.1, U6.12 (2E1), U6.13 (2E2)
unnamed: R29.1, U7.12 (2E1), U7.13 (2E2)
unnamed: R34.2, U8.4 (1E1), U8.5 (1E2)
unnamed: R35.2, R41.2, U8.6 (2A)
unnamed: R36.2, R37.2, U8.3 (1A)
unnamed: R38.2, U9.4 (1E1), U9.5 (1E2)
unnamed: R39.2, R45.2, U9.6 (2A)
unnamed: R40.2, R42.2, U9.3 (1A)
unnamed: R43.2, R46.2, U8.11 (3A)
unnamed: R44.2, R47.2, U8.14 (4A)
unnamed: R48.1, U8.12 (2E1), U8.13 (2E2)
unnamed: R51.2, R53.2, U9.11 (3A)
unnamed: R52.2, R54.2, U9.14 (4A)
unnamed: R55.1, U9.12 (2E1), U9.13 (2E2)
VCC0: C5.1, C6.1, C8.1, C10.1, U6.1 (VCC2), U6.9 (VCC3), U7.1 (VCC2), U7.9 (VCC3), U8.1 (VCC2), U8.9 (VCC3), U9.1 (VCC2), U9.9 (VCC3); also elsewhere on the board
VDD: C3.1, C4.1, C7.1, C9.1, R6.1, R7.1, R8.1, R9.1, R10.1, R11.1, R24.1, R25.1, R26.1, R27.1, R28.2, R29.2, R34.1, R35.1, R36.1, R38.1, R39.1, R40.1, R46.1, R47.1, R48.2, R53.1, R54.1, R55.2, U6.16 (VCC1), U7.16 (VCC1), U8.16 (VCC1), U9.16 (VCC1); also elsewhere on the board

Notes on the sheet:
16x connections to onboard FET drivers
${REV}
GND wires deliberately N/C; use star ground through battery rather than create ground loop
Signal inverter and 3V3-to-12V0 voltage shifter
12V from bank 0 regulator
16x signal connections from logic module
5V0 from onboard regulator
Signal input processing from logic module
${REV_DATE}

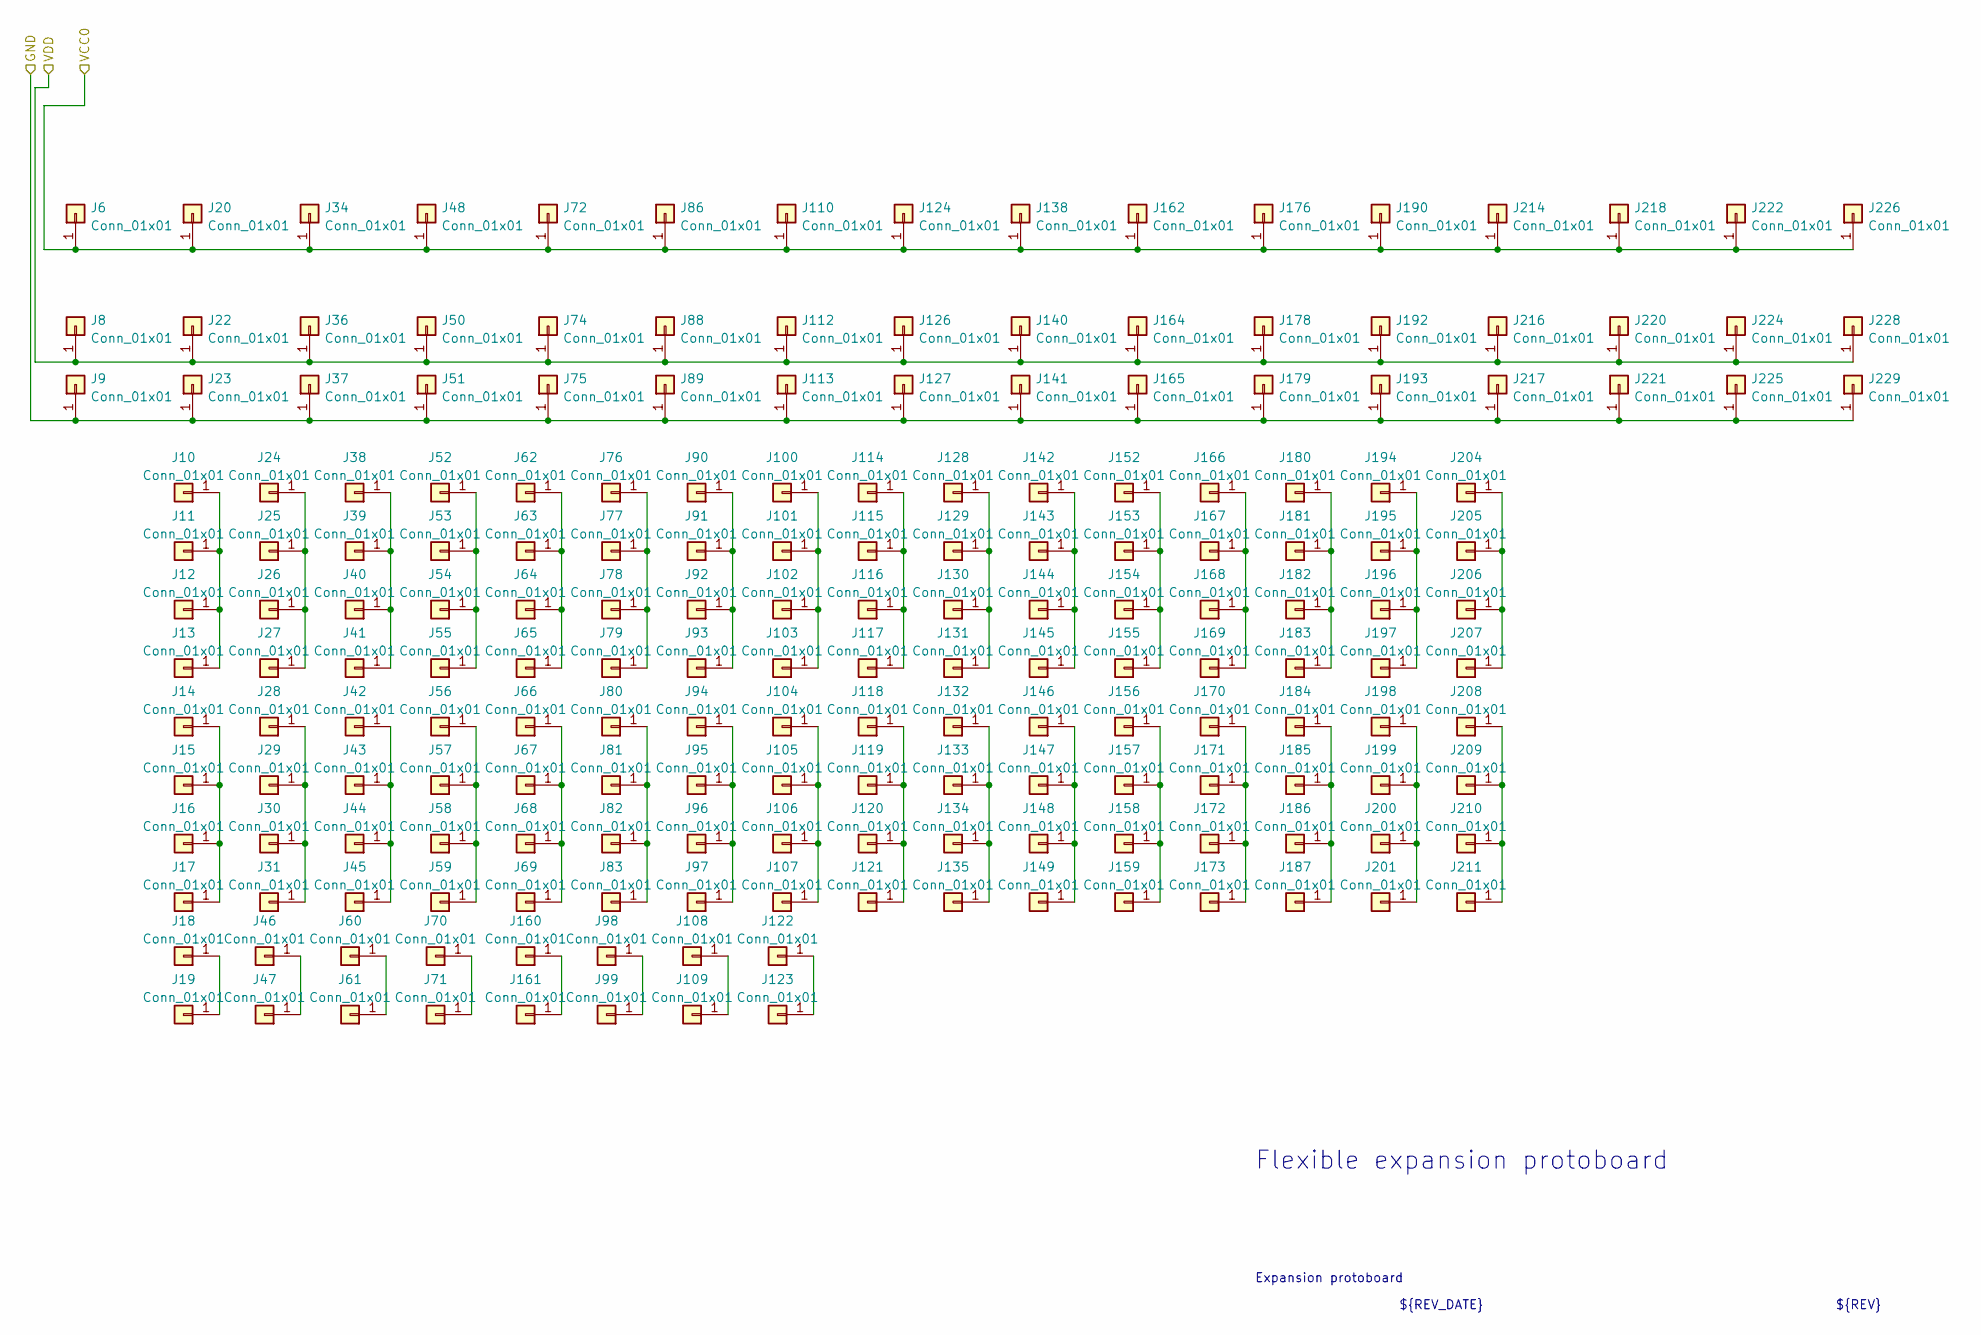
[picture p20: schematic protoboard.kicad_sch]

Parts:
J6, J8, J9, J10, J11, J12, J13, J14, J15, J16, J17, J19, J20, J22, J23, J24, J25, J26, J27, J28, J29, J30, J31, J34, J36, J37, J38, J39, J40, J41, J42, J43, J44, J45, J47, J48, J50, J51, J52, J53, J54, J55, J56, J57, J58, J59, J61, J62, J63, J64, J65, J66, J67, J68, J69, J71, J72, J74, J75, J76, J77, J78, J79, J80, J81, J82, J83, J86, J88, J89, J90, J91, J92, J93, J94, J95, J96, J97, J99, J100, J101, J102, J103, J104, J105, J106, J107, J109, J110, J112, J113, J114, J115, J116, J117, J118, J119, J120, J121, J123, J124, J126, J127, J128, J129, J130, J131, J132, J133, J134, J135, J138, J140, J141, J142, J143, J144, J145, J146, J147, J148, J149, J152, J153, J154, J155, J156, J157, J158, J159, J161, J162, J164, J165, J166, J167, J168, J169, J170, J171, J172, J173, J176, J178, J179, J180, J181, J182, J183, J184, J185, J186, J187, J190, J192, J193, J194, J195, J196, J197, J198, J199, J200, J201, J204, J205, J206, J207, J208, J209, J210, J211, J214, J216, J217, J218, J220, J221, J222, J224, J225, J226, J228, J229: Conn_01x01; 1mm_PTH_No_Silk
J18, J46, J60, J70, J98, J108, J122, J160: Conn_01x01; 1.6mm_PTH_No_Silk

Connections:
GND: J9.1, J23.1, J37.1, J51.1, J75.1, J89.1, J113.1, J127.1, J141.1, J165.1, J179.1, J193.1, J217.1, J221.1, J225.1, J229.1; also elsewhere on the board
unnamed: J10.1, J11.1, J12.1, J13.1
unnamed: J14.1, J15.1, J16.1, J17.1
unnamed: J18.1, J19.1
unnamed: J24.1, J25.1, J26.1, J27.1
unnamed: J28.1, J29.1, J30.1, J31.1
unnamed: J38.1, J39.1, J40.1, J41.1
unnamed: J42.1, J43.1, J44.1, J45.1
unnamed: J46.1, J47.1
unnamed: J52.1, J53.1, J54.1, J55.1
unnamed: J56.1, J57.1, J58.1, J59.1
unnamed: J60.1, J61.1
unnamed: J62.1, J63.1, J64.1, J65.1
unnamed: J66.1, J67.1, J68.1, J69.1
unnamed: J70.1, J71.1
unnamed: J76.1, J77.1, J78.1, J79.1
unnamed: J80.1, J81.1, J82.1, J83.1
unnamed: J90.1, J91.1, J92.1, J93.1
unnamed: J94.1, J95.1, J96.1, J97.1
unnamed: J98.1, J99.1
unnamed: J100.1, J101.1, J102.1, J103.1
unnamed: J104.1, J105.1, J106.1, J107.1
unnamed: J108.1, J109.1
unnamed: J114.1, J115.1, J116.1, J117.1
unnamed: J118.1, J119.1, J120.1, J121.1
unnamed: J122.1, J123.1
unnamed: J128.1, J129.1, J130.1, J131.1
unnamed: J132.1, J133.1, J134.1, J135.1
unnamed: J142.1, J143.1, J144.1, J145.1
unnamed: J146.1, J147.1, J148.1, J149.1
unnamed: J152.1, J153.1, J154.1, J155.1
unnamed: J156.1, J157.1, J158.1, J159.1
unnamed: J160.1, J161.1
unnamed: J166.1, J167.1, J168.1, J169.1
unnamed: J170.1, J171.1, J172.1, J173.1
unnamed: J180.1, J181.1, J182.1, J183.1
unnamed: J184.1, J185.1, J186.1, J187.1
unnamed: J194.1, J195.1, J196.1, J197.1
unnamed: J198.1, J199.1, J200.1, J201.1
unnamed: J204.1, J205.1, J206.1, J207.1
unnamed: J208.1, J209.1, J210.1, J211.1
VCC0: J6.1, J20.1, J34.1, J48.1, J72.1, J86.1, J110.1, J124.1, J138.1, J162.1, J176.1, J190.1, J214.1, J218.1, J222.1, J226.1; also elsewhere on the board
VDD: J8.1, J22.1, J36.1, J50.1, J74.1, J88.1, J112.1, J126.1, J140.1, J164.1, J178.1, J192.1, J216.1, J220.1, J224.1, J228.1; also elsewhere on the board

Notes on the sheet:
Expansion protoboard
${REV}
Flexible expansion protoboard
${REV_DATE}

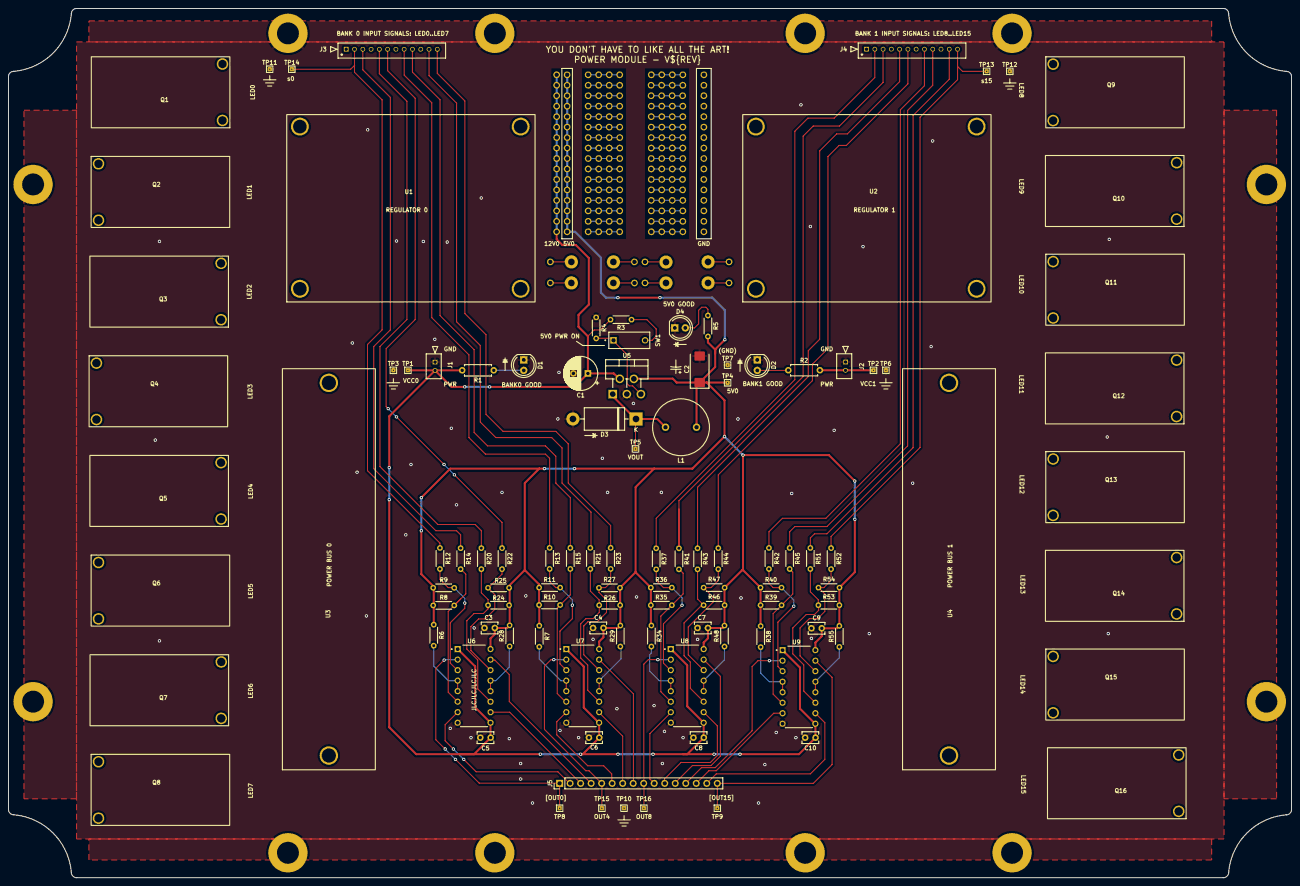
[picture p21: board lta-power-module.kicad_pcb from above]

Board: 2 copper layers, 310.0 x 210.0 mm, 311 parts (0 on the bottom side), 106 nets.

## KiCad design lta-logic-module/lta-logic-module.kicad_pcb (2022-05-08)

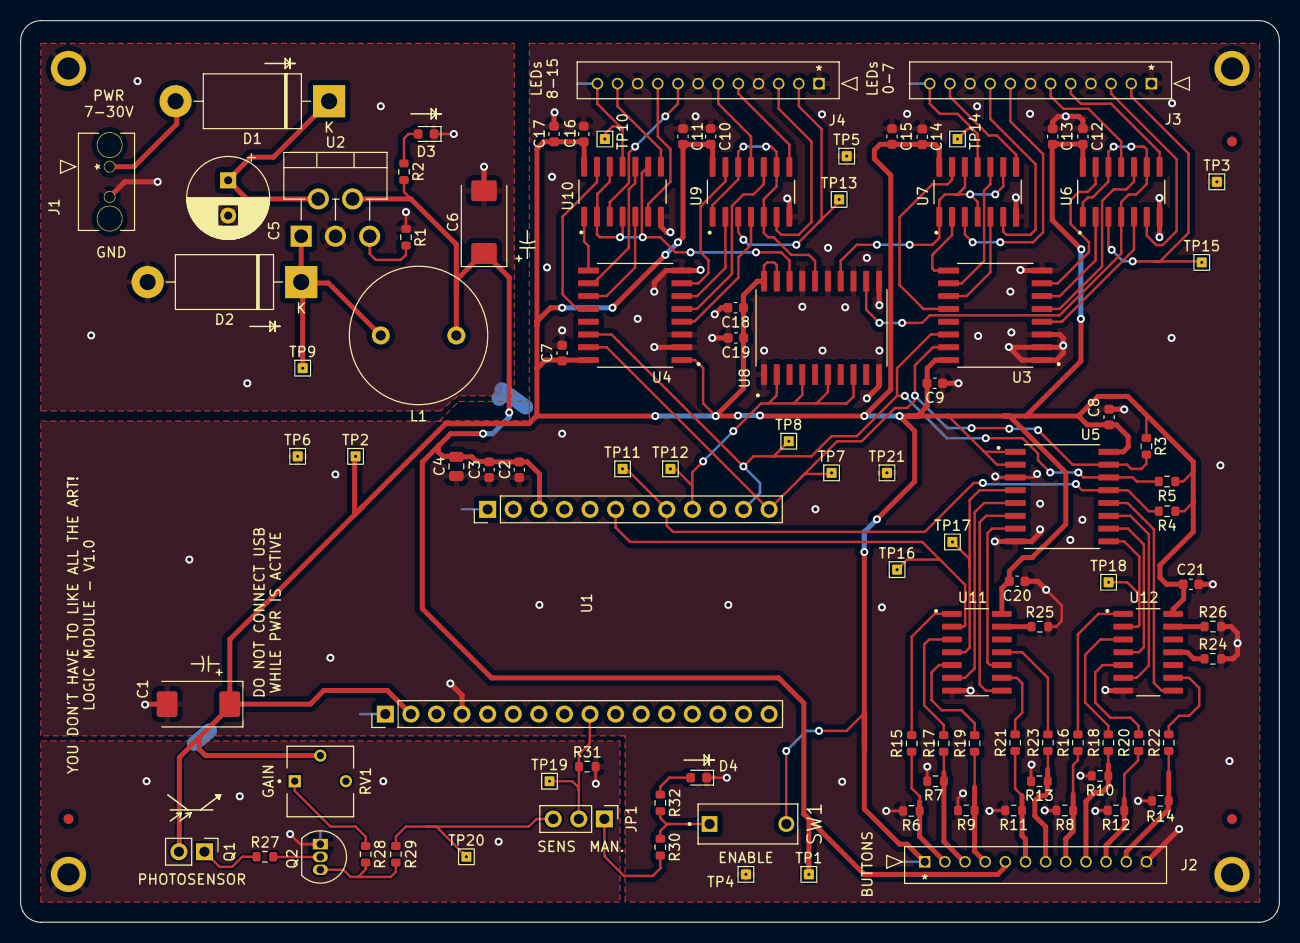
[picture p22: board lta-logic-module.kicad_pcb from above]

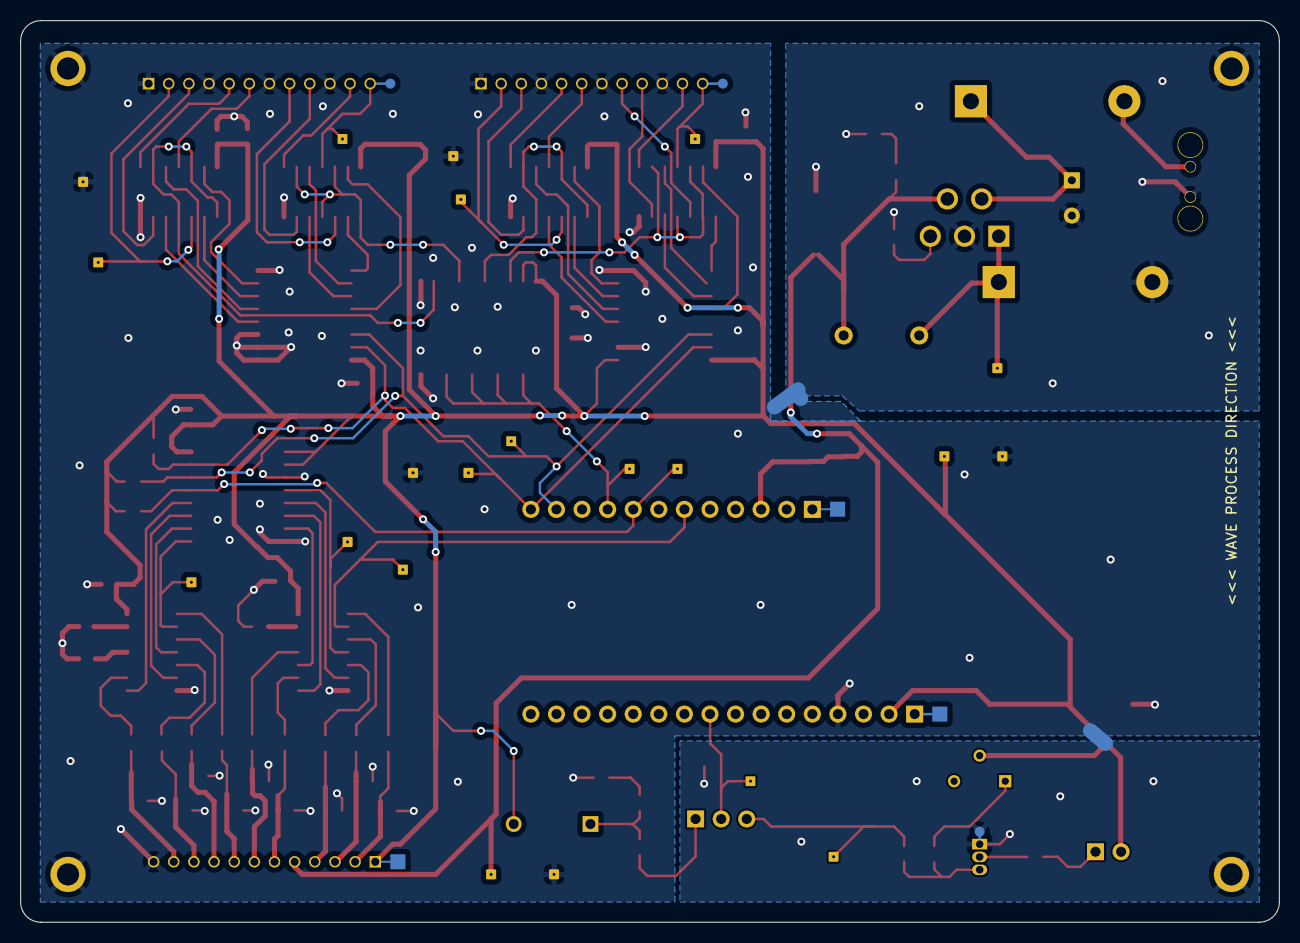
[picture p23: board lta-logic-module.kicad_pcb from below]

Board: 2 copper layers, 125.0 x 89.5 mm, 113 parts (6 on the bottom side), 89 nets.

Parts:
C1: 22u; CP_EIA-7343-30_AVX-N
C2, C7, C8, C9, C10, C12, C14, C16, C19, C20, C21: 100n; C_0603_1608Metric
C3, C11, C13, C15, C17, C18: 1u; C_0603_1608Metric
C4: 4u7; C_0805_2012Metric
C5: 220u; CP_Radial_D8.0mm_P3.50mm
C6: 68u; CP_EIA-7343-30_AVX-N
D1: SB5100; D_DO-201AD_P15.24mm_Horizontal
D2: SB530; D_DO-201AD_P15.24mm_Horizontal
D3: PWR; LED_0603_1608Metric
D4: DARK_EN; LED_0603_1608Metric
FID1, FID2, FID3: Fiducial; Fiducial_1mm_Mask2mm
H1, H2, H3, H4: MountingHole_Pad; MountingHole_2.2mm_M2_ISO7380_Pad
J1: Molex-MicroFit_43650-0218; Molex-Microfit-43650-0218
J2, J3, J4: Molex-MicroLatch_53253-1270; Molex-MicroLatch-53253-1270
JP1: Jumper_3_Open; PinHeader_1x03_P2.54mm_Vertical
L1: 150u; L_Radial_D13.5mm_P7.50mm
Q1: PT334-6B; PinHeader_1x02_P2.54mm_Vertical
Q2: 2N3904; TO-92_Inline
R1, R6, R7, R8, R9, R10, R11, R12, R13, R14, R24, R25, R26: 10K; R_0603_1608Metric
R2: 330R; R_0603_1608Metric
R3, R4, R5, R27, R30: 4K7; R_0603_1608Metric
R15, R16, R17, R18, R19, R20, R21, R22, R23, R28: 470R; R_0603_1608Metric
R29: 220R; R_0603_1608Metric
R31: 220K; R_0603_1608Metric
R32: 120R; R_0603_1608Metric
RV1: 25K; TRIM_3362P
SW1: SW_SPST; CUI-DIP-SW_DS01-254-x-01xx
TP1, TP2, TP3, TP4, TP5, TP6, TP7, TP8, TP9, TP10, TP11, TP12, TP13, TP14, TP15, TP16, TP17, TP18, TP19, TP20, TP21: TestPoint_Flag; TestPoint_THTPad_1.0x1.0mm_Drill0.3mm
TP22, TP23, TP26: Thief; Pad_1.5x1.5mm
TP24, TP25, TP27: Thief; Pad_D1.0mm
U1: Feather_M4_Express; Arduino_Feather_M4_Express_PinHeaders
U2: LM2595T-5; TO-220-5_P3.4x3.7mm_StaggerOdd_Lead3.8mm_Vertical-SilkFix
U3, U4, U5: PCF8574DW; TI_SOIC_DW0016A
U6, U7, U9, U10: SN74LVC00AD; TI_SOIC_D_R-PDSO-G14
U8: SN74LVC244ADWR; TI_SOIC_DW0020A
U11, U12: SN74LVC14AD; TI_SOIC_D_R-PDSO-G14

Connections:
+3V3: C1.1, C7.2, C8.2, C9.2, C10.2, C11.2, C12.2, C13.2, C14.2, C15.2, C16.2, C17.2, C18.1, C19.1, C20.2, C21.2, J2.1, Q1.2 (C), R3.1, R4.1, R5.1, RV1.2, SW1.2 (B), TP2.1, TP26.1, U1.2 (3V3), U3.16 (VDD), U4.1 (A0), U4.16 (VDD), U5.1 (A0), U5.2 (A1), U5.16 (VDD), U6.14 (VCC), U7.14 (VCC), U8.19 (~2OE), U8.20 (VCC), U9.14 (VCC), U10.14 (VCC), U11.14 (VCC), U12.14 (VCC)
+BATT: C5.1, D1.1 (K), U2.2 (VIN)
/5V0 (1A) Regulator/VOUT: D2.1 (K), L1.2, TP9.1, U2.1 (OUT)
/Button Inputs/btn_buf0: R15.2, U11.1 (1A)
/Button Inputs/btn_buf1: R17.2, U11.3 (2A)
/Button Inputs/btn_buf2: R19.2, U11.5 (3A)
/Button Inputs/btn_buf3: R21.2, U11.9 (4A)
/Button Inputs/btn_buf4: R23.2, U11.11 (5A)
/Button Inputs/btn_buf5: R16.2, U12.1 (1A)
/Button Inputs/btn_buf6: R18.2, U12.3 (2A)
/Button Inputs/btn_buf7: R20.2, U12.5 (3A)
/Button Inputs/btn_buf8: R22.2, U12.9 (4A)
/Button Inputs/btn_in0: J2.2, R6.1, R15.1
/Button Inputs/btn_in1: J2.3, R7.1, R17.1
/Button Inputs/btn_in2: J2.4, R9.1, R19.1
/Button Inputs/btn_in3: J2.6, R11.1, R21.1
/Button Inputs/btn_in4: J2.7, R13.1, R23.1
/Button Inputs/btn_in5: J2.8, R8.1, R16.1
/Button Inputs/btn_in6: J2.9, R10.1, R18.1
/Button Inputs/btn_in7: J2.10, R12.1, R20.1
/Button Inputs/btn_in8: J2.11, R14.1, R22.1
/DARK: JP1.2 (C), R31.1, TP19.1, U1.9 (A4)
/LED Signal Outputs/EN0: U6.1 (1A), U6.4 (2A), U6.9 (3A), U6.12 (4A), U8.12 (1Y4)
/LED Signal Outputs/EN1: U7.1 (1A), U7.4 (2A), U7.9 (3A), U7.12 (4A), U8.14 (1Y3)
/LED Signal Outputs/EN2: U8.16 (1Y2), U9.1 (1A), U9.5 (2B), U9.9 (3A), U9.12 (4A)
/LED Signal Outputs/EN3: U8.18 (1Y1), U10.2 (1B), U10.4 (2A), U10.9 (3A), U10.12 (4A)
/LED Signal Outputs/s0: J3.2, TP15.1, U6.3 (1Y)
/LED Signal Outputs/s1: J3.3, U6.6 (2Y)
/LED Signal Outputs/s2: J3.5, U6.8 (3Y)
/LED Signal Outputs/s3: J3.6, U6.11 (4Y)
/LED Signal Outputs/s4: J3.8, U7.3 (1Y)
/LED Signal Outputs/s5: J3.9, U7.6 (2Y)
/LED Signal Outputs/s6: J3.11, U7.8 (3Y)
/LED Signal Outputs/s7: J3.12, TP14.1, TP24.1, U7.11 (4Y)
/LED Signal Outputs/s8: J4.2, TP13.1, U9.3 (1Y)
/LED Signal Outputs/s9: J4.3, U9.6 (2Y)
/LED Signal Outputs/s10: J4.5, U9.8 (3Y)
/LED Signal Outputs/s11: J4.6, U9.11 (4Y)
/LED Signal Outputs/s12: J4.8, U10.3 (1Y)
/LED Signal Outputs/s13: J4.9, U10.6 (2Y)
/LED Signal Outputs/s14: J4.11, U10.8 (3Y)
/LED Signal Outputs/s15: J4.12, TP10.1, TP25.1, U10.11 (4Y)
/LED_EN: TP12.1, U1.20 (D6), U8.2 (1A1), U8.4 (1A2), U8.6 (1A3), U8.8 (1A4)
/Light-level sensor/DARK_SENS: JP1.3 (B), R29.2, TP20.1
/SCL: R5.2, TP8.1, U1.18 (SCL), U3.14 (SCL), U4.14 (SCL), U5.14 (SCL)
/SDA: R3.2, TP7.1, U1.17 (SDA), U3.15 (SDA), U4.15 (SDA), U5.15 (SDA)
/button0: TP16.1, U1.23 (D11), U11.2 (1Y)
/button1: TP17.1, U5.4 (P0), U11.4 (2Y)
/button2: U5.5 (P1), U11.6 (3Y)
/button3: U5.6 (P2), U11.8 (4Y)
/button4: U5.7 (P3), U11.10 (5Y)
/button5: TP18.1, U5.9 (P4), U12.2 (1Y)
/button6: U5.10 (P5), U12.4 (2Y)
/button7: U5.11 (P6), U12.6 (3Y)
/button8: U5.12 (P7), U12.8 (4Y)
/led0: U3.6 (P2), U6.2 (1B)
/led1: U3.4 (P0), U6.5 (2B)
/led2: U3.5 (P1), U6.10 (3B)
/led3: U3.7 (P3), U6.13 (4B)
/led4: U3.9 (P4), U7.2 (1B)
/led5: U3.11 (P6), U7.5 (2B)
/led6: U3.10 (P5), U7.10 (3B)
/led7: U3.12 (P7), U7.13 (4B)
/led8: U4.6 (P2), U9.2 (1B)
/led9: U4.4 (P0), U9.4 (2A)
/led10: U4.5 (P1), U9.10 (3B)
/led11: U4.7 (P3), U9.13 (4B)
/led12: U4.9 (P4), U10.1 (1A)
/led13: U4.11 (P6), U10.5 (2B)
/led14: U4.10 (P5), U10.10 (3B)
/led15: U4.12 (P7), U10.13 (4B)
/~BUTTON_INT_L: R4.2, TP11.1, U1.21 (D9), U5.13 (~INT)
GND: C1.2, C2.1, C3.1, C4.1, C5.2, C6.2, C7.1, C8.1, C9.1, C10.1, C11.1, C12.1, C13.1, C14.1, C15.1, C16.1, C17.1, C18.2, C19.2, C20.1, C21.1, D2.2 (A), D3.1 (K), D4.1 (K), H1.1, H2.1, H3.1, H4.1, J1.2, J2.12, J3.1, J3.4, J3.7, J3.10, J4.1, J4.4, J4.7, J4.10, Q2.1 (E), R1.1, R6.2, R7.2, R8.2, R9.2, R10.2, R11.2, R12.2, R13.2, R14.2, R24.2, R25.2, R26.2, R31.2, TP3.1, TP4.1, TP5.1, TP6.1, TP21.1, TP27.1, U1.4 (GND), U2.3 (GND), U3.1 (A0), U3.2 (A1), U3.3 (A2), U3.8 (VSS), U4.2 (A1), U4.3 (A2), U4.8 (VSS), U5.3 (A2), U5.8 (VSS), U6.7 (GND), U7.7 (GND), U8.1 (~1OE), U8.10 (GND), U8.11 (2A1), U8.13 (2A2), U8.15 (2A3), U8.17 (2A4), U9.7 (GND), U10.7 (GND), U11.7 (GND), U12.7 (GND)
unnamed: D1.2 (A), J1.1
unnamed: D3.2 (A), R2.1
unnamed: D4.2 (A), R32.2
unnamed: JP1.1 (A), R30.2
unnamed: Q1.1 (E), R27.1
unnamed: Q2.2 (B), R27.2
unnamed: Q2.3 (C), R28.2, R29.1
unnamed: R1.2, U2.5 (~ON/OFF)
unnamed: R24.1, U12.11 (5A)
unnamed: R25.1, U11.13 (6A)
unnamed: R26.1, U12.13 (6A)
unnamed: R28.1, RV1.1
unnamed: R30.1, R32.1, SW1.1 (A)
unnamed: TP22.1, U1.1 (RESET)
unnamed: TP23.1, U1.28 (VBATT)
VDD: C2.2, C3.2, C4.2, C6.1, J2.5, L1.1, R2.2, TP1.1, U1.26 (VUSB), U2.4 (FB)

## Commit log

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2022-04-26 Start sketching out schematic.
    Add layout for Quad LED Driver.
    Add placeholders for other subcircuits.
    [5V_regulator.kicad_sch, button_inputs.kicad_sch, like-the-art.kicad_sch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]
2022-04-30 Add schematic for button inputs and I2C signal busses.
    * Define 9x button inputs
    * Define I2C parallel bus expanders used for FET output signals
    and button inputs
    * Add (empty) schematic for 5V switching regulator.
    [5V_regulator.kicad_sch, button_inputs.kicad_sch, i2c_comms.kicad_sch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]
2022-04-30 Add PI3740-based prototype 12V buck/boost regulator.
    Add 12V buck/boost regulator schematic based on 3x PI3740 regulators.
    Each PI3740 can deliver 6A.
    This circuit was intended for operation with VIn = 11.5--14.4V
    and not used after I switched to VIn centered at 24V.
    [12V_regulator.kicad_sch]
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2022-05-02 Sketch out ISL8117-driven 12V regulator.
    Another candidate entry for on-board 12V regulation is to
    build our own based on the reference schematic from the ISL8117
    DC buck regulator controller datasheet.
    Implemented (most of) this reference schematic here.
    [12V_regulator.kicad_sch, button_inputs.kicad_sch, i2c_comms.kicad_sch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]
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2022-05-02 Make copy of schematics as lta-power-module.
    Make separate KiCAD projects for LTA "logic" and "power" modules
    which will be on separate PCBs.
    [12V_regulator.kicad_sch, 5V_regulator.kicad_sch, button_inputs.kicad_sch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]
2022-05-03 Full sketch of logic module schematic.
    - Add button inputs
    - Add LED signal driver / PWM combination
    - Add 5V regulator based on LM2592
    [12V_regulator.kicad_sch, 5V_regulator.kicad_sch, LED_signals.kicad_sch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]
2022-05-03 Fix ERC violations.
    [5V_regulator.kicad_sch, LED_signals.kicad_sch, button_inputs.kicad_sch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]
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2022-05-03 Initial PCB setup
    * Configure Elecrow DRC checks for lta-logic-module.
    * Switch SN74LVC244A from 'N' PDIP to 'DWR' SOIC footprint.
    [5V_regulator.kicad_sch, LED_signals.kicad_sch, button_inputs.kicad_sch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]
2022-05-04 Add light sensor circuit.
    Adjust TODOs and comments after testing btn circuit.
    [5V_regulator.kicad_sch, LED_signals.kicad_sch, button_inputs.kicad_sch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]
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2022-05-06 Fix all the footprint data.
    Somehow my footprint info got clobbered. Reset a bunch of symbol
    properties to empty... this info is now all back in place.
    * Added 3 fiducial marks
    * Added 4 mounting holes
    [5V_regulator.kicad_sch, light_sensor.kicad_sch, lta-logic-module.kicad_sch]
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2022-05-06 Relocated optosensor to south side of board.
    * Moved optosensor logic away from the USB plug-side of the Feather.
    You can now plug in USB while the Feather is attached to the board.
    * Changed schematic such that `button0` now goes directly to the
    Feather; buttons 1--8 are on the I2C bus. Cleans up some obnoxious
    routing.
    * Optimized other routing & GND fill.
    [i2c_comms.kicad_sch, lta-logic-module.kicad_pcb, lta-logic-module.kicad_sch]
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2022-05-08 Isolated ground planes for AGND and DGND.
    * Analog optosensor now has isolated ground plane area.
    * Moved 3V3 load capacitor behind U1 to keep its return
    fully on digital ground.
    [lta-logic-module.kicad_pcb]
2022-05-08 Fix GND path return.
    * Route power traces over ground plane.
    * Add routed corners to edge cuts
    * Remove final TODO notes.
    [5V_regulator.kicad_sch, LED_signals.kicad_sch, button_inputs.kicad_sch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]
2022-05-08 Add indicator LED to SW1 enabled.
    Adds 220K pull-down resistor to DARK signal. (Validated.)
    Update solder thief pads and process direction indicator.
    [5V_regulator.kicad_sch, LED_signals.kicad_sch, button_inputs.kicad_sch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]
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2022-05-09 Power module main electrical schematic drawn, unannotated.
    A logical schematic including flying wire connections between off-board
    modules is sketched in the associated pptx file.
    [5V_regulator.kicad_sch, lta-power-module.kicad_sch, protoboard.kicad_sch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]
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2022-05-10 Remove unnecessary LEDs.
    The MOSFET drivers have LEDs which will operate based on the gate
    signal alone; we can just rely on those.
    [lta-power-module.kicad_sch, protoboard.kicad_sch, signals_in.kicad_sch]
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2022-05-11 Considerably more work on power module PCB.
    * Slight reorganization of layout.
    * Routed all traces.
    [5V_regulator.kicad_sch, lta-power-module.kicad_pcb, lta-power-module.kicad_sch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]
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2022-05-11 Work on border.
    * Add perimeter edge cut to fit WH-22 polycase.
    * Add M5 mounting holes in temp locations on PCB.
    * Lay out and lock left-edge M5 mounting holes.
    [lta-power-module.kicad_pcb, lta-power-module.kicad_sch, protoboard.kicad_sch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]
2022-05-15 Lay out all mounting holes.
    * All DRC checks passing.
    * Fix footprint silkscreen conflicts.
    * Fix ext. regulator module symbol.
    [lta-power-module.kicad_pcb, lta-power-module.kicad_sch]
2022-05-15 NPTHs and test points.
    * Added NPTH defs to `User.Eco1` layer in footprints.
    * Renamed `User.Eco1` to `Mechanical` in PCB layout.
    * Duplicated `Edge Cuts` onto `Mechanical` layer.
    *Use `Mechanical` as `.GKO` layer, not `Edge Cuts`!*
    * Added test points for key signals.
    [lta-power-module.kicad_pcb, lta-power-module.kicad_sch, signals_in.kicad_sch]
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2022-05-16 Switched to plated through-holes for all mounting.
    Ready for release to manufacturing.
    [lta-power-module.kicad_pcb, lta-power-module.kicad_sch]
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2022-05-16 Add top-level README.
    * Copy logic module BOM from only in finished fab-run folder to have a
    working copy in the logic module working dir.
    * Add rendered views of power module 1.0 PCB and PCBA.
    [LTA Logic module - complete BOM.xlsx]
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2022-06-05 Update board for D4M.
    * Fix layout violation: Move SMT components 2.5mm+ from edge.
    * Update MPN/SPNs for resistors to use correct JLC basic library parts.
    [mosfet-chip.kicad_pcb, mosfet-chip.kicad_sch]
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2022-08-09 Logic Mod: Add self-test switch; bump to v1.1 for development.
    * Add a push-button (SPST, NO) switch wired from Arduino D4 to GND to
    trigger admin mode and start a self-test cycle.
    This has been retrofitted on the active board via rework but could be
    integrated on the PCB for v1.1.
    * Version number incremented to 1.1 for next development cycle
    * Release date set to unreleased.
    [lta-logic-module.kicad_sch]

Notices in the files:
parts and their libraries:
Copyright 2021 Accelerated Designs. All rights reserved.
